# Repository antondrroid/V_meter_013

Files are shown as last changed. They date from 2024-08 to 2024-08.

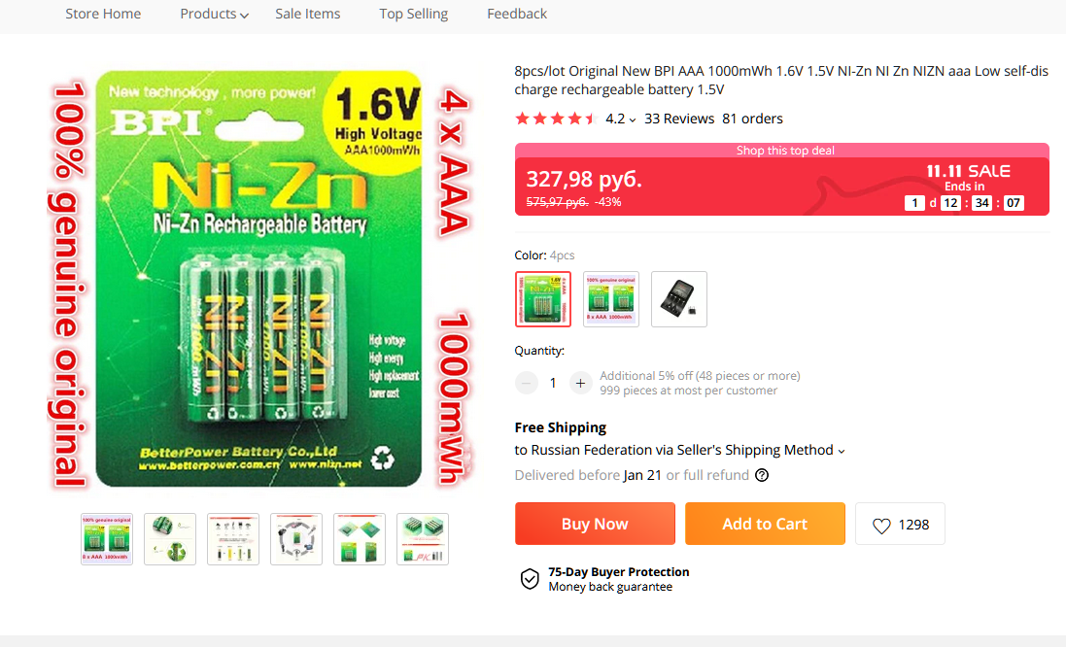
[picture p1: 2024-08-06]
Spare_parts/orders_china_2and3_boards/2021-11-11 22_25_46-8pcs_lot Original New BPI AAA 1000mWh 1.6V 1.5V NI Zn NI Zn NIZN aaa Low self di.png

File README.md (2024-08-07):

# test

hange at remoe and pull to the load.

the somebody edit project

one more time indeendent editing

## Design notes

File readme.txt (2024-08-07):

Initializing a Git repository
the first step is to initialize a Git repository. 

    Open Git Bash.

    Navigate to the root directory of your project.

    Initialize the EMPTY  local directory as a Git repository. By default, the initial branch is called main.

    If you’re using Git 2.28.0 or a later version, you can set the name of the default branch using -b.

    git init -b main

    if this is old git directry, it will reinitialized and in this case need to change owner:
 
              git config --global --add safe.directory D:/projects_old/V_meter/V_meter_013

    Add the files in your new local repository. This stages them for the first commit.

    $ git add .
    # Adds the files in the local repository and stages them for commit. To unstage a file, use 'git reset HEAD YOUR-FILE'.

    Commit the files that you've staged in your local repository.

    $ git commit -m "First commit"
    # Commits the tracked changes and prepares them to be pushed to a remote repository. To remove this commit and modify the file, use 'git reset --soft HEAD~1' and commit and add the file again.

    Adding a local repository to GitHub using Git

Before you can add your local repository to GitHub using Git, you must authenticate to GitHub on the command line. For more information, see "About authentication to GitHub."

    Create a new repository on GitHub.com. To avoid errors, do not initialize the new repository with README, license, or gitignore files. You can add these files after your project has been pushed to GitHub. For more information, see "Creating a new repository."

    At the top of your repository on GitHub.com's Quick Setup page, click 

    to copy the remote repository URL. for example, it will be:

    https://github.com/antondrroid/test_new_local_repository.git

    Screenshot of the "Quick Setup" header in a repository. Next to the remote URL, an icon of two overlapping squares is highlighted with an orange outline.

    Open Git Bash.

    Change the current working directory to your local project.

    To add the URL for the remote repository where your local repository will be pushed, run the following command. Replace REMOTE-URL with the repository's full URL on GitHub.

    git remote add origin https://github.com/antondrroid/test_new_local_repository.git

    For more information, see "Managing remote repositories."

    To verify that you set the remote URL correctly, run the following command.

    git remote -v

answer must be looks like:

            PS D:\projects_old\test_new_local_repository> git remote -v
            origin  https://github.com/antondrroid/test_new_local_repository.git (fetch)
            origin  https://github.com/antondrroid/test_new_local_repository.git (push)

    To push the changes in your local repository to GitHub.com, run the following command.

    git push origin main
if not work, try 
          git push origin /  git push -u origin main
if say:
fatal: The current branch ain has no upstream branch.
To push the current branch and set the remote as upstream, use
       
        git push --set-upstream origin ain

    If your default branch is not named "main," replace "main" with the name of your default branch. For more information, see "About branches."

if remote branch was changed and local has changed too, undepenentaly,
for example, you create in remote file readme.md, but no pushed your loal files to remote yet,
so you has 3 files on local server and one only on remote! 

 use:

PS D:\projects_old\test> git pull origin main
From https://github.com/antondrroid/test
 * branch            main       -> FETCH_HEAD
fatal: refusing to merge unrelated histories  (not syncronized changes, and pull not work as usual)
PS D:\projects_old\test> ls

    Directory: D:\projects_old\test

Mode                 LastWriteTime         Length Name
----                 -------------         ------ ----
d-----          8/6/2024   4:13 PM                contract
-a----          8/6/2024   3:21 PM           3235 readme.txt
-a----          8/6/2024   1:31 PM              0 depth_of_commits.txt

PS D:\projects_old\test> git pull origin main --allow-unrelated-histories
From https://github.com/antondrroid/test
 * branch            main       -> FETCH_HEAD
Merge made by the 'ort' strategy.
 README.md | 1 +
 1 file changed, 1 insertion(+)
 create mode 100644 README.md
PS D:\projects_old\test> ls

after that , use 

git push -u origin main 

and README.MD will be pulled to local server. 

    Directory: D:\projects_old\test

Mode                 LastWriteTime         Length Name
----                 -------------         ------ ----
d-----          8/6/2024   4:13 PM                contract
-a----          8/6/2024   3:21 PM           3235 readme.txt
-a----          8/6/2024   1:31 PM              0 depth_of_commits.txt
-a----          8/6/2024   5:22 PM              8 README.md

if somebody edit he project, while you are trip to  home, and after come, begin edit project, not pul 
before, you will cannot nor pull, nor push.

Further reading

    "Adding a file to a repository"
    "Troubleshooting the 2 GB push limit"

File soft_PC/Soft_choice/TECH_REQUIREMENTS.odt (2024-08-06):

# Состав стенда.

Вольтметр В7-78 c USBtMC портом (3510А) и плата коммутации, управляемая микроконтроллером.

# Описание работы устройства

Вольтметр имеет выход сигнала синхронизации, управляемый командной «триггер», подключеный к входу синхронизации на плате коммутации, которая по команде с микроконтроллера переключает тестовфые выводы на очередную пару контрольнфх точек.

Вольтметр подключен при помощи USB порта к PC.

На PC запускается программа состоящая из пакета команд SPCI, которые конфигурируют установки волтьметра перед измерением, запускают измерение и считывают результтат в файл для последующей обработки результатов. Последней командой в пакете является вызов триггера, в результате которого на выход синхронизации вольтметра подается импульс, воспринимаемый контроллером платы как сигнал к переключению тестовых выводов к следующей паре контрольнфх точек.

# Требования к программному обеспечению

Программное обеспечение представляет собой среду программирования, которая позволяет записывать и хранить пакеты команд SCPI, передавать их через Rs-232 или USBинтерфейс в вольтметр, и принимать результаты измерений и записывать их в любом распостраненном формате в файл для возможности последующей обработки.

<без использования каких либо других языков программирования (JAVA, phyton, C++)>

Желательно в одном из форматов OPEN office / libre office, так как предполагается в дальнейшем изспользовать для работы установки LINUX. Если такого не существует, то в любом из форматов WINDOWS.

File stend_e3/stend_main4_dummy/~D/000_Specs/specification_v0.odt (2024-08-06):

Изм. | Лист | № докум. | Подп. | Дата
Разраб. | | | | | | Лит. | | | Лист | Листов
Пров. | | | | | | | | | 1 | 6
Н.контр.
Утв.

Подп. и дата
Инв. № дубл.
Взам. инв. №
Подп. и дата
Инв. № подл.

Перв. примен.
Справ. №

Копировал

Формат А4

Формат | Зона | Поз. | Обозначение | Наименование | Кол. | Примечание
| | | | Утвержден
| | | | -УД

| | | | | | Лист
| | | | | | 2
Изм. | Лист | № докум. | Подп. | Дата

Подп. и дата
Инв. № дубл.
Взам. инв. №
Подп. и дата
Инв. № подл.

Копировал

Формат А4

Формат | Зона | Поз. | Обозначение | Наименование | Кол. | Примечание

| | | | | | Лист
| | | | | | 3
Изм. | Лист | № докум. | Подп. | Дата

Подп. и дата
Инв. № дубл.
Взам. инв. №
Подп. и дата
Инв. № подл.

Копировал

Формат А4

Формат | Зона | Поз. | Обозначение | Наименование | Кол. | Примечание

Формат | Зона | Поз. | Обозначение | Наименование | Кол. | Примечание

Формат А4

Копировал

Подп. и дата
Инв. № дубл.
Взам. инв. №
Подп. и дата
Инв. № подл.

| | | | | | Лист
| | | | | | 4
Изм. | Лист | № докум. | Подп. | Дата

| | | | | | Лист
| | | | | | 5
Изм. | Лист | № докум. | Подп. | Дата

Подп. и дата
Инв. № дубл.
Взам. инв. №
Подп. и дата
Инв. № подл.

Копировал

Формат А4

Формат | Зона | Поз. | Обозначение | Наименование | Кол. | Примечание

Лист регистрации изменений
Изм. | Номера листов (страниц) | | | | Всего листов (страниц) в докум. | № докум. | Входящий № сопрово- дительного докум. и дата | Подп. | Дата
| изме- ненных | заме- ненных | новых | аннули- рованных

Формат А4

Копировал

Подп. и дата
Инв. № дубл.
Взам. инв. №
Подп. и дата
Инв. № подл.

| | | | | | Лист
| | | | | | 6
Изм. | Лист | № докум. | Подп. | Дата

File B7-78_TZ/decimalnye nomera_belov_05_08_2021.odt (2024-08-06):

RUST.ZM-12.400.00.00 Seebeck measurement system (longitudinally).

Вот таков номер (подчеркнуто) и наименование стенда измерения альфа стержней.

Для механической части: RUST.ZM-12.401.00.00, которая разбивается на RUST.ZM-12.401.01.ХХ, RUST.ZM-12.401.02.УУ

И т.д.

Вам (электронной составляющей) достается номер RUST.ZM-12.402.00.00, который можете разбивать как вам удобно в части 4-х последних цифр.

Далее в состав стенда войдет 3-х контурный термостат со своим источником управления температурой и обеспечением циркуляцией 3-х контуров:

1 контур – внешний - оборотная вода на производстве предприятия.

2 контур - горячий (30 градсов) контур стенда

3 контур – холодный (20 градусов) контур стенда

Мы не будем переделывать всю имеющуюся документация под американский вариант (во всяком случае сейчас).

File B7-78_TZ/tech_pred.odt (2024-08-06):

# Техническое предложение

## по разработке измерительного стенда на основе вольтметра В7-78 с возможностью автоматического измерения параметров в нескольких контрольных точках.

## 1.Состав изделия

Изделие состоит из следующих компонентов :

1.Плата коммутации, предназначенная для переключения измерительных контактов вольтметра на различные контрольные точки.

Переключение осуществляется при помощи механических реле, управляемых микроконтроллером АТМЕГА 328. Управление микроконтроллером осуществляется по программе, предусматривающей передачу управляющих команд от компьютера PC1 на вольтметр MES1 через USB port по интерфейсу USART (RS232), а также использующий внешние входы синхронизации вольтметра MES1.

2.Компьютер PC1, управляющий процессом измерения при помощи команд SCPI, согласно программе написанной на языке С++, а также сохраняющий результаты измерений в виде файла (таблицы) на жестком диске.

3.Вольтметр В7-78, подключенный к плате коммутации измерительными выводами и компьютеру через USB порт.

## 2.Принцип работы изделия.

К выводам каналов коммутационной платы подключаются контрольные точки, в которых необходимо замерить напряжение. Количество контрольных точек неограничено, и хотя в данном проекте предусмотрено 6 каналов, их число может быть увеличено до более чем 32000 (при применении данного контроллера).

После включения питания стенда, запускается программа на компьютере, которая последовательно переключает измерительные выводы к очередному каналу и передает в вольтметр через USB port набор команд SCPI, которые управляют непосредственно процессом измерения параметров для данной контрольной точки и сохраняют результаты в файл на жестом диске компьютера.

###### 3.Предлагаемый порядок работы.

После уточнения ТЗ разрабатывается принципиальная схема*, разводка печатной платы и изготавливается макет платы.

Во время изготовления макета платы проводятся работы по программному обеспечению.

С.Михайлов

*На схеме соединение MCU с каналами управления показаны условно (т.е.пунктиром)

contacts:

т. 89011892586 (whatsupp)

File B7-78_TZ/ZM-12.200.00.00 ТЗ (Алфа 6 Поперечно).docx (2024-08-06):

ZM-12.200.00.00 ТЗ (Алфа 6 Поперечно).

ТЗ.

Назначение

Стенд ZM-12.200.00.00 предназначен для измерения коэффициента термо-эдс (α - К Зеебека) слитков синтезированного термоэлектрического материала на основе теллурида висмута и в форме цилиндров Ø30мм и длиной 140мм. Коэффициента термо-эдс дальнейшем - α.

α удельная величина, определяемая как отношение напряжения (разницы потенциалов) возникающего между двумя участками материала к разнице температур между этими участками. α =(U1-U2)/ΔT

α может быть, как положительной, так и отрицательной величиной в зависимости от типа проводимости материала.

Определение α осуществляется путем измерения:

- разницы потенциалов между двумя точками полупроводника,

- измерения разницы температур между этими точками.

Конструкция теплового узла

Механическая часть стенда представляет собой 2 блока из 12 изложниц каждый в форме полуцилиндрических колец. Температура полуколец одного блока от температуры полуколец второго блока отличается на ~10°С. Всего измеряется 6 слитков. Слитки в процессе измерения находятся между медными полукольцами с различной температурой, причем к слитку прижимается 4 полукольца – по 2-а кольца с одной и другой стороны слитка (слитки в форме стержней диаметром 30мм). Кольца создают разницу температур между боковыми поверхностями слитков с одной и другой стороны каждого из слитков. Температура полуколец поддерживается 2-я водяными контурами. Вода каждого из контуров прокачивается по полукольцам одного из блоков, а ризница температур теплоносителя поддерживается специальным термоэлектрическим блоком. Проток теплоносителя обеспечивается 2-я циркуляционными насосами. В контур с более теплым носителем встроен радиатор с вентилятором, что позволяет сохранять общую среднюю температуру измерений.

В полукольца вмонтированы и подключены как дифференциальный (т.е. навстречу друг другу) термопары, так что можно определить разницу температур между каждыми из 12 пар колец, прилегающими с каждой из сторон слитков. Помимо термопар вмонтированы зонды в виде подпружиненных иголок, по 2-е пары на 2 полукольца.

Алгоритм измерения следующий:

1. Всего в одном цикле измерений определяется термо-эдс 12 слитков. Все 12 слитков относятся к одному процессу синтеза термоэлектрического материала.
2. Укладываются первые 6 слитков на полукольца одного из блоков (холодного) так, что к каждому из слитков прилегает «холодное» полукольцо в начале и в конце слитка. Слитки лежат горизонтально.
3. На 6 слитков опускается блок с ответными 12-ю полукольцами - «горячими». Конструктивно обеспечено, что холодные и горячие кольца расположены встречно образуя 2-а полукольца (горячего и холодного) вокруг слитка. Полукольца подпружинены, для обеспечения хорошего теплового контакта между медными полукольцами и слитками.
4. Время выдержки для стабилизации тепловых условий составляет приблизительно 10 минут.
5. После термостабилизации осуществляется серия автоматических измерений каждое из которых относится к одному из 6-и слитков:
1) Измеряется термо-эдс дифференциальной термопары Uтп (~400мкм) с одной стороны слитка. Значение всегда положительно. Это определяет температуру между горячим и холодным полукольцом с одной стороны слитка.
2) Измеряется разница потенциалов между 2-я парами зондов (от -2000 до +2000мкм) с этой же стороны слитка.
3) Измеряется термо-эдс дифференциальной термопары со второй стороны слитка.
4) Измеряется разница потенциалов между 2-я парами со второй стороны слитка.
6. Измерение по п.4 проводится 6 раз.
7. Далее делается новая закладка из 6-и слитков и измерения по п. 5 и 6 повторяются.

База данных:

В базу данных заносится

1. Дата проведения измерений.
2. Номер процесса синтеза (например 1N3451), состоящий из 3-х идентификационных значений: |X|Y| ZZZZ |

X=1 или 2 или 3 указывает на исходные материалы (первичный синтез, сплавление возвратных материалов и пр до 9.)

Y=N или P указывает тип проводимости синтезируемого материала (только 2-а варианта).

Z= порядковый номер процесса для каждого из сочетаний 1-й и 2-й позиции своя нумерация: т.е. 1N0001, 1P0001, 2N0001, 2P0001…

3. Порядковый номер слитка данного процесса 1…12. Т.е. каждому слитку соответствует не только номер процесса, но и номер слитка в данном процессе.
4. Для каждого слитка соответственно добавляется еще начало и конец слитка.
5. В базу данных измерений заносятся значения измеряемых величин в соответствии с номером процесса, номером слитка и началом или концом слитка.
6. Вместо измеряемых величин в базу данных можно заносить: относящиеся к этому номеру процесса, номеру слитка и позиции в слитке (начало или конец слитка) значения термо-эдс, вычисляемые по формуле:

α 1н= (U11н-U1.2н)/ΔT1н

α 1к= (U11к-U1.2к)/ΔT1к

α 2н= (U21н-U22н)/ΔT2н

α 2к= (U21к-U22к)/ΔT2к

………………………

α12н =(U12.1н-U12.2н)/ΔT12н

α12к =(U12.1к-U12.2к)/ΔT12к

Значение ΔТ определяется из формулы ΔТ= Uтп/40. Для каждого конкретного измерения ΔT1н= U(тп)1н/40.

………………. и т.д. с соответствующими идексами

ΔT12н= U(тп)12н/40.

Значение ΔТ составляет приблизительно 10°С.

7. Значение α должно иметь размерность [мкв/°C]. Ориентировочный диапазон значений от—200 до +200мкм/°С
8. Запрос к базе данных может быть по одному из 3-х параметров или по их сочетанию. Дополнительно необходимо ввести еще 1-о поле для запроса, в котором может быть однозначное число (0-9).

Конструкция блока измерений (электронная часть).

1. Коммутация при переключении измеряемых величин должна осуществляться механическими реле или герконами. Это исключит сетевые и прочие помехи.
2. Измерительная часть должна базироваться на стандартном приборе милливольтметр типа В7-78/2.
3. Точность определяемого значения α должна быть не менее 2% по показаниям электронных приборов. Не учитывается погрешность теплового узла ячеек стенда. Т.е. не учитываем качество тепловых контактов и потерь теплового напора на теплопереходах.
4. Показания значений измеряемых величин (напряжения) должны быть видимы в процессе измерения на цифровой панели измеряющего вольтметра.
5. Вычисленные значения на основании измеряемых величин должны отражаться в протоколе измерений с вычислением среднего значения вычисляемой величины (α) на мониторе компьютера и должна иметься возможность печати протокола.
6. Необходимо иметь протокол по запросу и возможность его напечатать.

Варианты запросов (к базе данных) пока не обсуждались, но для запросов в базе данных достаточно заданного соответствия измеряемых (вычисляемых) величин с идентификатором: дата, тип материалов исходных материалов(X), тип проводимости (Y), номер процесса (ZZZZ), порядковый номер слитка в процессе (1-12), начало и конец слитка.

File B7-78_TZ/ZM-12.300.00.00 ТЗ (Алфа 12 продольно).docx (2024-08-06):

ZM-12.300.00.00 ТЗ (Алфа 12 Продольно).

ТЗ.

Назначение

Стенд ZM-12.300.00.00 предназначен для измерения коэффициента термо-эдс (α - К Зеебека) экструдированных стержней термоэлектрического материала на основе теллурида висмута и в форме цилиндров Ø30мм и длиной 240мм. Коэффициента термо-эдс дальнейшем - α.

α удельная величина, определяемая как отношение напряжения (разницы потенциалов) возникающего между двумя участками материала к разнице температур между этими участками. α =(U1-U2)/ΔT

α может быть, как положительной, так и отрицательной величиной в зависимости от типа проводимости материала.

Определение α осуществляется путем измерения:

- разницы потенциалов между двумя точками полупроводника,

- измерения разницы температур между этими точками.

Конструкция теплового узла

Механическая часть стенда представляет собой 12 ячеек в каждую из которых устанавливается стержень. Каждый стержень устанавливается вертикально на медны блок, температура которого 20гр.С К верхней части стержня прижимается медный блок имеющий температуру 30гр.С. Блоки создают разницу температур между торцевыми поверхностями стержней. Температура блоков поддерживается 2-я водяными контурами. Ризница температур теплоносителя поддерживается специальным термоэлектрическим блоком. Проток теплоносителя обеспечивается 2-я циркуляционными насосами. Температура горячего контура поддерживается специальным блоком управления.

В блоки вмонтированы и подключены как дифференциальный (т.е. навстречу друг другу) термопары, так что можно определить разницу температур между каждыми из 12 пар блоков, прилегающими с каждом из торцов слитков. Помимо термопар к блокам подведены провода, между холодным и горячим блоком каждого стержня (ячейки соответственно) возникает термо-эдс в результате разницы температур (Эффект Зеебека).

Задача: измерить возникающие потенциалы между блоками для каждого стержня и эдс дифференциальной термопары этих блоков, т.е. разницы эдс горячей и холодной термопары..

Алгоритм измерения следующий:

1. Всего в одном цикле измерений определяется термо-эдс 12 слитков. Все 12 слитков относятся к одному процессу экструзии термоэлектрического материала.
2. Устанавливается последовательно каждый из слетков между холодным и горячим блоком.
3. Время выдержки для стабилизации тепловых условий составляет приблизительно 10 минут.
4. После термостабилизации осуществляется серия автоматических измерений каждое из которых относится к одному из 12-и стержней:
1) Измеряется термо-эдс дифференциальной термопары Uтп (~400мкV) с одной стороны слитка. Значение всегда положительно. Это определяет температуру между горячим и холодным полукольцом с одной стороны слитка по формуле: ΔT= Uтп/40
2) Измеряется разница потенциалов между 2-я блоками Uα (от -3000 до +3000мкV) для этого стержня.
5. Измерение по п.1) и 2) проводится 12 раз.
6. В процессе измерения формируется файл относящийся к данному процессу экструзии.

База данных:

В базу данных заносится

1. Дата проведения измерений.
2. Номер процесса экструзии (например 1N3451), состоящий из 3-х идентификационных значений: |X|Y| ZZZZ |

X=1 или 2 или 3 указывает на исходные материалы (первичный синтез, сплавление возвратных материалов и пр до 9.)

Y=N или P указывает тип проводимости синтезируемого материала (только 2-а варианта).

Z= порядковый номер процесса для каждого из сочетаний 1-й и 2-й позиции своя нумерация: т.е. 1N0001, 1P0001, 2N0001, 2P0001…

3. Порядковый номер слитка данного процесса 1…12. Т.е. каждому слитку соответствует не только номер процесса, но и номер слитка в данном процессе.
4. В базу данных измерений заносятся значения измеряемых величин в соответствии с номером процесса и номером слитка.
5. Вместо измеряемых величин в базу данных можно заносить: относящиеся к этому номеру процесса и номеру слитка значения удельной термо-эдс, вычисляемые по формуле:

α 1= Uα1/ ΔT1

α 2= Uα2/ ΔT2

………………………

α 12= Uα12/ ΔT12

Значение ΔТ определяется из формулы ΔТ= Uтп/40. Для каждого конкретного измерения ΔTх= U(тп)х/40.

Значение ΔТ составляет приблизительно 10°С.

6. Значение α должно иметь размерность [мкV/°C]. Ориентировочный диапазон значений от—200 до +200мкм/°С
7. Запрос к базе данных может быть по одному из 3-х параметров или по их сочетанию. Дополнительно необходимо ввести еще 1-о поле для запроса, в котором может быть однозначное число (0-9).

Конструкция блока измерений (электронная часть).

1. Коммутация при переключении измеряемых величин должна осуществляться механическими реле или герконами. Это исключит сетевые и прочие помехи.
2. Измерительная часть должна базироваться на стандартном приборе милливольтметр типа В7-78/2.
3. Точность определяемого значения α должна быть не менее 2% по показаниям электронных приборов. Не учитывается погрешность теплового узла ячеек стенда. Т.е. не учитываем качество тепловых контактов и потерь теплового напора на теплопереходах.
4. Показания значений измеряемых величин (напряжения) должны быть видимы в процессе измерения на цифровой панели измеряющего вольтметра.
5. Вычисленные значения на основании измеряемых величин должны отражаться в протоколе измерений с вычислением среднего значения вычисляемой величины (α) на мониторе компьютера и должна иметься возможность печати протокола.
6. Необходимо иметь протокол по запросу и возможность его напечатать.

Варианты запросов (к базе данных) пока не обсуждались, но для запросов в базе данных достаточно заданного соответствия измеряемых (вычисляемых) величин с идентификатором: дата, тип материалов исходных материалов(X), тип проводимости (Y), номер процесса (ZZZZ), порядковый номер слитка в процессе (1-12), начало и конец слитка.

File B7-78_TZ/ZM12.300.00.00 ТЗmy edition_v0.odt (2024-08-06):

Проект ТЗ.

Разработка блока коммутации для измерительного комплекса

RUST.ZM-12.400.00.00 Seebeck measurement system (longitudinally)

1. Назначение

Блок коммутации предназначен для переключения измерительных контактов измерительного прибора( ИП), входящего в состав комплекса (вольтметра В7-78) между 24 контрольными точками и передачи информации в память входящего в состав комплекса персонального компьютера (ПК), под управлением ОС MS Windows, с подключенным локальным (ЛП) или сетевым принтером (СП) для печати протокола измерений.

2. Принцип работы изделия

Переключения производятся при помощи электромагнитных реле, управляемых при помощи микроконтроллера, который после переключения на очередную контрольную точку дает команду на считывание показаний ИП через интерфейс USB в память ПК, с формированием текстового файла «24.txt».

3. Формат текстового файла

Текстовый файл состоит из строк, по количеству числа измерений. Всего 24 строки.

Первая запись в строке — порядковый номер контрольной точки, в которой проводилось измерение.

Вторая запись — отладочная информация, которая не должна учитываться при дальнейшей работе

Третья запись — значение показания прибора в текущей контрольной точке.

4. Формат показаний прибора и пределы измерений

Пределы измерений прибора устанавливаются в пределах 3000 μV.

запись показаний производится в експоненциальной форме в виде мантиссы и десятичной дроби.

5. Наименование и обозначение изделия.

Изделию присваивается наименование «Блок коммутации» и обозначение «RUST.ZM-12.402.00.00»

Составные части изделия , их наименование и их обозначения выбираются разработчиком, исходя из требований ЕСКД и единого классификатора Общероссийский классификатор изделий и конструкторских документов ОК 012-93

6. Документация

Комплект документации (КД) на изделие должен включать пакет документов, согласно правилам ескд, действующим на момент начала разработки (утверждения ТЗ)

7. Форм фактор.

Изделие размещается в отдельном корпусе из листового металла, на передней и задней панели размещаются выводы для подключения соединителей измерительных контактов, информационных интерфейсов.

На передней панели также размещаются кнопка включения питания изделия и индикатор включения питания изделия.

Корпус может быть использован от имеющейся модели блока либо вновь разработанный.

8. питание

Питание изделия производится от электрической сети с параметрами 220 В, 50 Гц.

9. Перечень имеющихся сокращений

ИП измерительный прибор

КД конструкторская документация

ЛП Локальный принтер

ПК персональный компьютер

СП сетевой принтер

10. Приложения
1. Распечатка образца протокола измерений - 1лист.
2. Эскизная схема соединений комплекса RUST.ZM-12.400.00.00 , с подключенным блоком измерений RUST.ZM-12.402.00.00 .

Утверждаю

Ген. Директор ООО Рустек …..................................

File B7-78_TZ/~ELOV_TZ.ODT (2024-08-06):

1. После термостабилизации осуществляется серия автоматических измерений каждое из которых относится к одному из 6-и слитков:

2. этот пункт предусматривает изучение работы данного вольтметра в автоматическом режиме, а также изучение его языка управления, для этого мне необходимо иметь тестовы1 экземпляр прибора со всей документацией. (если конечно имеется такая возможность, так как в режиме outsourcing на вашей территории я его изучать пока не могу)

3. управление устройством коммутации при помощи MCU не представляет для меня сложности, т..е процесс будет представлять собой поочередное подключение измерительного оборудования к каждому слитку на определенное время синхронизированное с процессом измерения, делаемых вольтметром согласно программе. Такое устройство я могу спроектировать сделать печатную плату и отладить программу контроллера, (полагаю на это уйдет 2 недели или даже больше) но сначала мне необходимо получить информацию по п.2. Имеется ли у вас возможность передать мне данный прибор или есть специалист, который находится в курсе дела и будет заниматься данной частью работы.

4. есть ли у вас предпочитаемая база данных радиоэлементов, чтобы я вибирал элементы для проекта из уже используемых вашей компанией для других изделий?(наверное можете мне передать для этого контакты одного из ваших инженеров - схемотехников. Я пользуюсь Altium Designer)

5. для сохранения целостности переписки прошу вас писать ответы внизу текста.

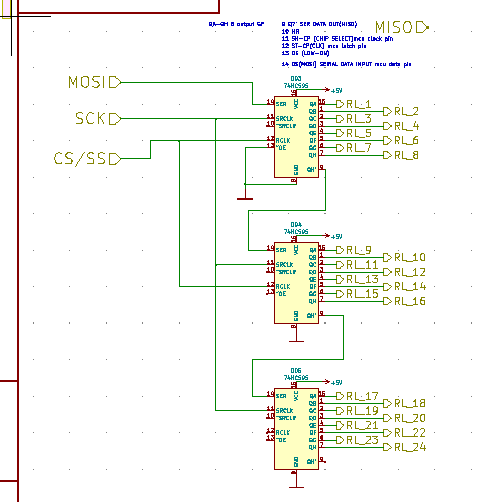
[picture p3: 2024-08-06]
stend_e3/stend_main4_dummy/~rawings/[stend_main_3_REGISTERS_] — Schematic Editor.png

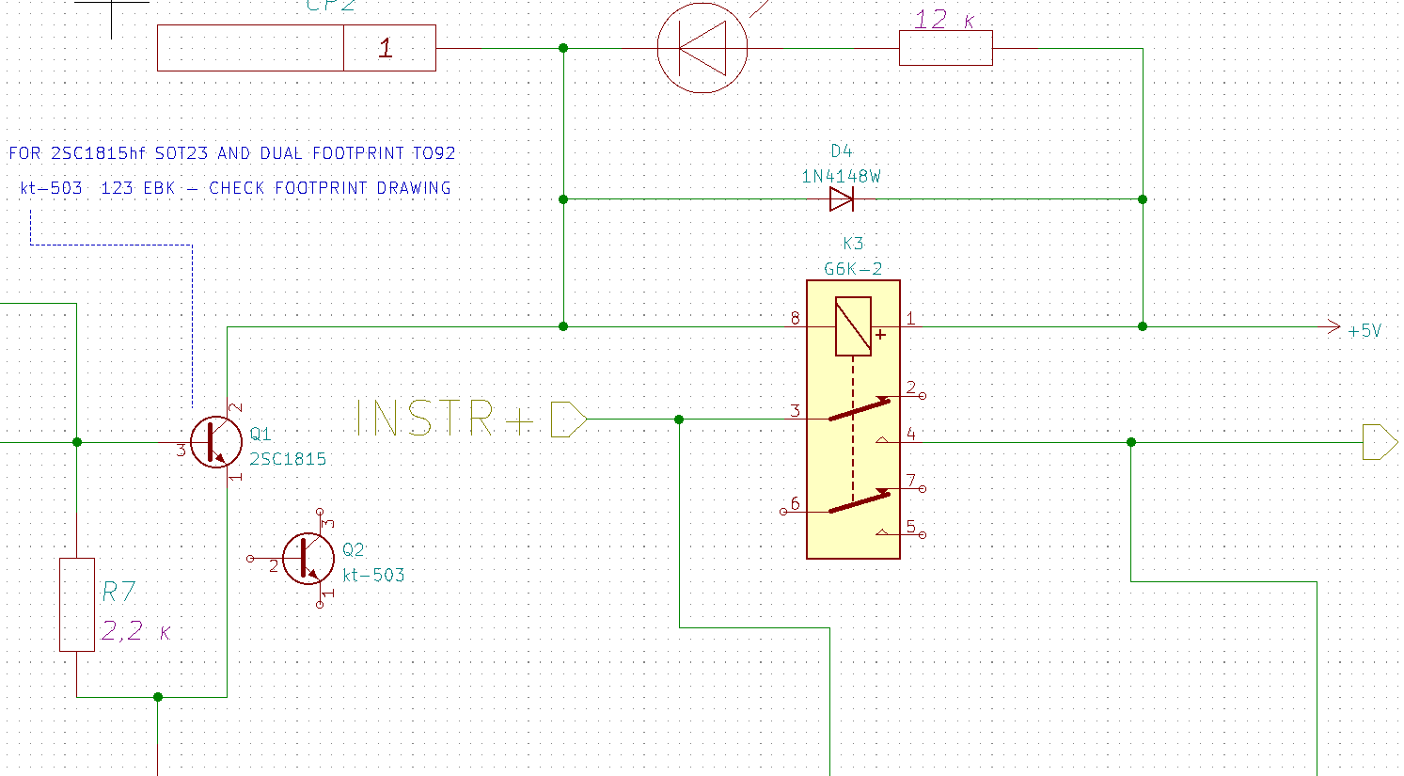
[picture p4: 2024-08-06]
stend_e3/stend_main3/~rawings/2021-09-02 12_52_29-_p5 [stend_main_5_RELAY1_G6K-2F-Y-5VDC_] — Schematic Editor.png

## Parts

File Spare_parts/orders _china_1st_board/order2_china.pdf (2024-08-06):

order2

Page 1

## Заказ 2

назначение | изделие RUST.ZM-12.402.00.00
наименование | Кол-во Цена руб
Модуль микроконтроллера | 2 | 520
Разьем BNC male | 5 | 160
кабель USB/USB B | 1 | 155
resistor 12kom 2 kom SMD (1 набор 300шт) | 1 | 130
resistor 12kom 2 kom углеродные (1 набор400шт)1 | 1 | 140
транзистор 2sc1815 набор 100шт1 | 1 | 105
всего: | 1210

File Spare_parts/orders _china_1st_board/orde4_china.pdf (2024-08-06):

order4

очки монтажные 1-5х | 1 | 1062
увеличительное стекло для часов, 6X, 10X, 15X, 20X, 25X | 1 | 1076
фен паяльный | 1 | 953
паяльная паста BST-510 | 35g | 193
паяльная паста CD LT-528 | 55g | 383
флюсовая паста NC-559-ASM | 3x10cc | 278
Оловянно-свинцовый припой, проволочный | 55g | 214

4159

## Заказ 4 -оборудование и расходные материалы

назначение | изделие RUST.ZM-12.402.00.00
наименование | Кол-во Цена руб

всего:

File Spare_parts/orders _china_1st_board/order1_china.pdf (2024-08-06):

Sheet1

Page 1

наименование | Кол-во | ценаб руб
Реле омрон G6K-2FY | 5 | 143
Реле омрон G6K-2FY | 10 | 315
Реле омрон G6K-2FY | 10 | 365
Реле Fujitsu A5WK | 5 | 288
светодиод SMD | 100 | 128
светодиод плоский | 100 | 98
| | 1337

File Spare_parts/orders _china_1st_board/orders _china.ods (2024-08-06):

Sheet: order1
наименование | Кол-во | ценаб руб
Реле омрон G6K-2FY | 5 | 143
Реле омрон G6K-2FY | 10 | 315
Реле омрон G6K-2FY | 10 | 365
Реле Fujitsu A5WK | 5 | 288
светодиод SMD 0805 | 100 | 128
светодиод плоский | 100 | 98
 |  | 1337

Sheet: order2
Заказ 2
назначение | изделие RUST.ZM-12.402.00.00
наименование | Кол-во | Цена руб
Модуль микроконтроллера | 2 | 520
Разьем BNC male | 5 | 262
кабель USB/USB B | 1 | 159
resistor 12kom 2 kom SMD (1 набор 300шт) | 1 | 130
resistor 12kom 2 kom углеродные (1 набор400шт)1 | 1 | 140
транзистор 2sc1815HF SOT23 набор 100шт1 | 1 | 105
10 штук Разъем PBS-1x16 (PBS-16)шаг 2.54 мм (https://www.aliexpress.ru/item/1005002562703691.html) | 1 | 147
XH2.54 /5/10 p 2,54 мм комплект разъем JST 10шт | 1 | 160
всего: |  | 1623

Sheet: order3
Заказ 3 -замена вместо чипа и дипа
назначение | изделие RUST.ZM-12.402.00.00
наименование | Кол-во | Цена руб
1N4148W SOD-123 | 100 | 92
всего: |  | 92
1N4148 SOD-123

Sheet: order4
Заказ 4 -оборудование и расходные материалы
назначение | изделие RUST.ZM-12.402.00.00
наименование | Кол-во | цена за ед. | Цена общая
очки монтажные 1-5х | 1 |  | 1062
увеличительное стекло для часов, 6X, 10X, 15X, 20X, 25X | 1 |  | 1076
фен паяльный | 1 |  | 953
паяльная паста BST-510 | 35g |  | 193
паяльная паста CD LT-528 | 55g |  | 383
флюсовая паста NC-559-ASM | 3x10cc |  | 278
Оловянно-свинцовый припой, проволочный | 55g |  | 214
гнездо DIP 28 конт, | 10 | 6.9 | 69
оптрон 817 DIP4 PC817 PC817C | 20 | 2.25 | 45
печатная плата макетная | 2 | 70 | 140
всего: |  |  | 4413

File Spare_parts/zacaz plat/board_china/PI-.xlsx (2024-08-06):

 |  |  |  |  | Proforma Invoice
PI NO:20210123-3407297A W202101211743716
Vendor : SHENZHEN JLC ELECTRONICS CO.,LTD. |  |  |  |  |  | Customer:
Contact Person:Roy Fu |  |  |  |  |  | Contact person:I
Tel :+86 755 2391 9769 |  |  |  |  |  | Tel:674609383
Email:support@jlcpcb.com |  |  |  |  |  | Email:
Address: |  |  |  |  |  | Billing Adrdress:
26th Floor, Olympics Building
Shangbao Road, Futian District |  |  |  |  |  | Peremohy
Shenzhen |  |  |  |  |  | 04136
Guangdong |  |  |  |  |  | UKRAINE
China
VAT:
 |  |  |  |  |  | VTA:123456
No. | Description | HS Code | Order No. | QTY |  |  | Unit Price | Amount
1 | PCB Batchs | 8534009000 | P1 | 500 |  |  | 0.2656 | 132.80
Total: |  |  |  |  |  |  |  | $916.70
Note:
 | 1, Payment terms: T/T 100% In Advanced.
 | 2, Customer shall be responsible for the possible transaction fee deducted by bank.
TT Bank Information
Beneficiary's Name: |  | SHENZHEN JLC ELECTRONICS CO.,LTD.
Bank Name: |  | INDUSTRIAL AND COMMERCIAL BANK OF CHINA SHENZHEN BRANCH
Bank Address: |  | North Block Financial Centre Shennan Road East Shenzhen,Guangdong,China
Swift Code: |  | ICBKCNBJSZN
Bank Number: |  | 4000021619090017542
 |  |  |  |  | Approved By |  |  | 2021-09-15

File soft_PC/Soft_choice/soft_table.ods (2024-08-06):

Name of soft | PRO | contra | functions | requirements | price | min price
teststand | emulator absent |  |  |  | $6,000.00 | $2,000.00
diadem | emulator absent |  |  |  | $5,000.00 | $2,000.00
labview | emulator |  |  |  | $6,000.00 | $2,000.00

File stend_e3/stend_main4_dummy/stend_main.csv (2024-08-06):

Source: | D:\V_meter_2\stend_e3\stend_main4_dummy\stend_main.kicad_sch
Date: | 10/23/2021 11:44:15 AM
Tool: | Eeschema (5.99.0-12829-gf2783a86e0)
Generator: | C:\Program Files\KiCad\5.99\bin\scripting\plugins/bom_csv_grouped_by_value.py
Component Count: | 356
Individual Components:
Item | Qty | Reference(s) | Value | LibPart | Footprint | Datasheet | PIN1 | PIN10 | PIN2 | PIN3 | PIN4 | PIN5 | PIN6 | PIN7 | PIN8 | PIN9 | ValueAnalog | ValueC | ValueGOST | ValueGroup | ValueManufacturer | ValueName | ValueNote | ValueSupplier | ValueTU | ValueTemp_1 | ValueTemp_2 | ValueTemp_3 | ValueTemp_4 | ValueTemp_5 | ValueTemperature | volume
 |  | BB1 | bread_16pins | my_Library:bread_16pins | my_Library_ftprint:breadboard_DIP-16_W7.62mm_Socket_LongPads | http://www.ti.com/lit/ds/symlink/sn74hc595.pdf
 |  | BB2 | bread_16pins | my_Library:bread_16pins | my_Library_ftprint:breadboard_DIP-16_W7.62mm_Socket_LongPads | http://www.ti.com/lit/ds/symlink/sn74hc595.pdf
 |  | BB3 | bread_16pins | my_Library:bread_16pins | my_Library_ftprint:breadboard_DIP-16_W7.62mm_Socket_LongPads | http://www.ti.com/lit/ds/symlink/sn74hc595.pdf
 |  | BB4 | bread_16pins | my_Library:bread_16pins | my_Library_ftprint:breadboard_DIP-16_W7.62mm_Socket_LongPads | http://www.ti.com/lit/ds/symlink/sn74hc595.pdf
 |  | BB5 | bread_16pins | my_Library:bread_16pins | my_Library_ftprint:breadboard_DIP-16_W7.62mm_Socket_LongPads | http://www.ti.com/lit/ds/symlink/sn74hc595.pdf
 |  | BB6 | bread_16pins | my_Library:bread_16pins | my_Library_ftprint:breadboard_DIP-16_W7.62mm_Socket_LongPads | http://www.ti.com/lit/ds/symlink/sn74hc595.pdf
 |  | BB7 | bread_16pins | my_Library:bread_16pins | my_Library_ftprint:breadboard_DIP-16_W7.62mm_Socket_LongPads | http://www.ti.com/lit/ds/symlink/sn74hc595.pdf
 |  | C1 | K53-68-C-20V-10uF-10% | [LTM][Capacitors][K53-68][A_B_C_D_E][5]:K53-68-C-20V-10uF-10% | [LTM][FP][Capacitors]:[LTM][C][Tantalum][C][6032-28] | C:/Program Files/KiCad/share/LTM_DataSheet/Конденсаторы_танталовые_К53-68_ОАО_Элеконд.pdf |  |  |  |  |  |  |  |  |  |  | SMD-TAN-C-10uF±10% | 10000000 | К53-68-C-20 В-10 мкФ ±10% | Конденсаторы | ф. ОАО "Элеконд" | 10 мкФ | - | ЗАО "Спец-электронкомплект" | АЖЯР.673546.007 ТУ | АЖЯР.673546.007 ТУ | - | - | - | - | от минус 60 ⁰C до + 125 ⁰C
 |  | CP1 | CP_L | my_Library:CP_L | my_Library_ftprint:PinHeader_1x01_P2.54mm_Vertical |  |  |  |  |  |  |  |  |  |  |  | PLD-10 DS-1021 |  | розетка СНП346-5PП21-1 | Соединители | ф. АО «Электродеталь» | ВИЛКА НА ПЛАТУ 2.5 ММ ШАГ | - | ф. АО «Электродеталь» | РЮМК.430420.011ТУ | РЮМК.430420.011ТУ | - | - | - | - | от минус 60 ⁰C до + 85 ⁰C
 |  | CP2 | CP_L | my_Library:CP_L | my_Library_ftprint:PinHeader_1x01_P2.54mm_Vertical |  |  |  |  |  |  |  |  |  |  |  | PLD-10 DS-1021 |  | розетка СНП346-5PП21-1 | Соединители | ф. АО «Электродеталь» | ВИЛКА НА ПЛАТУ 2.5 ММ ШАГ | - | ф. АО «Электродеталь» | РЮМК.430420.011ТУ | РЮМК.430420.011ТУ | - | - | - | - | от минус 60 ⁰C до + 85 ⁰C
 |  | CP3 | CP_L | my_Library:CP_L | my_Library_ftprint:PinHeader_1x01_P2.54mm_Vertical |  |  |  |  |  |  |  |  |  |  |  | PLD-10 DS-1021 |  | розетка СНП346-5PП21-1 | Соединители | ф. АО «Электродеталь» | ВИЛКА НА ПЛАТУ 2.5 ММ ШАГ | - | ф. АО «Электродеталь» | РЮМК.430420.011ТУ | РЮМК.430420.011ТУ | - | - | - | - | от минус 60 ⁰C до + 85 ⁰C
 |  | CP4 | CP_R | my_Library:CP_R | my_Library_ftprint:PinHeader_1x01_P2.54mm_Vertical |  |  |  |  |  |  |  |  |  |  |  | PLD-10 DS-1021 |  | розетка СНП346-5PП21-1 | Соединители | ф. АО «Электродеталь» | ВИЛКА НА ПЛАТУ 2.5 ММ ШАГ | - | ф. АО «Электродеталь» | РЮМК.430420.011ТУ | РЮМК.430420.011ТУ | - | - | - | - | от минус 60 ⁰C до + 85 ⁰C
 |  | CP5 | CP_L | my_Library:CP_L | my_Library_ftprint:PinHeader_1x01_P2.54mm_Vertical |  |  |  |  |  |  |  |  |  |  |  | PLD-10 DS-1021 |  | розетка СНП346-5PП21-1 | Соединители | ф. АО «Электродеталь» | ВИЛКА НА ПЛАТУ 2.5 ММ ШАГ | - | ф. АО «Электродеталь» | РЮМК.430420.011ТУ | РЮМК.430420.011ТУ | - | - | - | - | от минус 60 ⁰C до + 85 ⁰C
 |  | CP6 | CP_L | my_Library:CP_L | my_Library_ftprint:PinHeader_1x01_P2.54mm_Vertical |  |  |  |  |  |  |  |  |  |  |  | PLD-10 DS-1021 |  | розетка СНП346-5PП21-1 | Соединители | ф. АО «Электродеталь» | ВИЛКА НА ПЛАТУ 2.5 ММ ШАГ | - | ф. АО «Электродеталь» | РЮМК.430420.011ТУ | РЮМК.430420.011ТУ | - | - | - | - | от минус 60 ⁰C до + 85 ⁰C
 |  | CP7 | CP_L | my_Library:CP_L | my_Library_ftprint:PinHeader_1x01_P2.54mm_Vertical |  |  |  |  |  |  |  |  |  |  |  | PLD-10 DS-1021 |  | розетка СНП346-5PП21-1 | Соединители | ф. АО «Электродеталь» | ВИЛКА НА ПЛАТУ 2.5 ММ ШАГ | - | ф. АО «Электродеталь» | РЮМК.430420.011ТУ | РЮМК.430420.011ТУ | - | - | - | - | от минус 60 ⁰C до + 85 ⁰C
 |  | CP8 | CP_R | my_Library:CP_R | my_Library_ftprint:PinHeader_1x01_P2.54mm_Vertical |  |  |  |  |  |  |  |  |  |  |  | PLD-10 DS-1021 |  | розетка СНП346-5PП21-1 | Соединители | ф. АО «Электродеталь» | ВИЛКА НА ПЛАТУ 2.5 ММ ШАГ | - | ф. АО «Электродеталь» | РЮМК.430420.011ТУ | РЮМК.430420.011ТУ | - | - | - | - | от минус 60 ⁰C до + 85 ⁰C
 |  | CP9 | CP_L | my_Library:CP_L | my_Library_ftprint:PinHeader_1x01_P2.54mm_Vertical |  |  |  |  |  |  |  |  |  |  |  | PLD-10 DS-1021 |  | розетка СНП346-5PП21-1 | Соединители | ф. АО «Электродеталь» | ВИЛКА НА ПЛАТУ 2.5 ММ ШАГ | - | ф. АО «Электродеталь» | РЮМК.430420.011ТУ | РЮМК.430420.011ТУ | - | - | - | - | от минус 60 ⁰C до + 85 ⁰C
 |  | CP10 | CP_L | my_Library:CP_L | my_Library_ftprint:PinHeader_1x01_P2.54mm_Vertical |  |  |  |  |  |  |  |  |  |  |  | PLD-10 DS-1021 |  | розетка СНП346-5PП21-1 | Соединители | ф. АО «Электродеталь» | ВИЛКА НА ПЛАТУ 2.5 ММ ШАГ | - | ф. АО «Электродеталь» | РЮМК.430420.011ТУ | РЮМК.430420.011ТУ | - | - | - | - | от минус 60 ⁰C до + 85 ⁰C
 |  | CP11 | CP_L | my_Library:CP_L | my_Library_ftprint:PinHeader_1x01_P2.54mm_Vertical |  |  |  |  |  |  |  |  |  |  |  | PLD-10 DS-1021 |  | розетка СНП346-5PП21-1 | Соединители | ф. АО «Электродеталь» | ВИЛКА НА ПЛАТУ 2.5 ММ ШАГ | - | ф. АО «Электродеталь» | РЮМК.430420.011ТУ | РЮМК.430420.011ТУ | - | - | - | - | от минус 60 ⁰C до + 85 ⁰C
 |  | CP12 | CP_R | my_Library:CP_R | my_Library_ftprint:PinHeader_1x01_P2.54mm_Vertical |  |  |  |  |  |  |  |  |  |  |  | PLD-10 DS-1021 |  | розетка СНП346-5PП21-1 | Соединители | ф. АО «Электродеталь» | ВИЛКА НА ПЛАТУ 2.5 ММ ШАГ | - | ф. АО «Электродеталь» | РЮМК.430420.011ТУ | РЮМК.430420.011ТУ | - | - | - | - | от минус 60 ⁰C до + 85 ⁰C
 |  | CP13 | CP_L | my_Library:CP_L | my_Library_ftprint:PinHeader_1x01_P2.54mm_Vertical |  |  |  |  |  |  |  |  |  |  |  | PLD-10 DS-1021 |  | розетка СНП346-5PП21-1 | Соединители | ф. АО «Электродеталь» | ВИЛКА НА ПЛАТУ 2.5 ММ ШАГ | - | ф. АО «Электродеталь» | РЮМК.430420.011ТУ | РЮМК.430420.011ТУ | - | - | - | - | от минус 60 ⁰C до + 85 ⁰C
 |  | CP14 | CP_L | my_Library:CP_L | my_Library_ftprint:PinHeader_1x01_P2.54mm_Vertical |  |  |  |  |  |  |  |  |  |  |  | PLD-10 DS-1021 |  | розетка СНП346-5PП21-1 | Соединители | ф. АО «Электродеталь» | ВИЛКА НА ПЛАТУ 2.5 ММ ШАГ | - | ф. АО «Электродеталь» | РЮМК.430420.011ТУ | РЮМК.430420.011ТУ | - | - | - | - | от минус 60 ⁰C до + 85 ⁰C
 |  | CP15 | CP_L | my_Library:CP_L | my_Library_ftprint:PinHeader_1x01_P2.54mm_Vertical |  |  |  |  |  |  |  |  |  |  |  | PLD-10 DS-1021 |  | розетка СНП346-5PП21-1 | Соединители | ф. АО «Электродеталь» | ВИЛКА НА ПЛАТУ 2.5 ММ ШАГ | - | ф. АО «Электродеталь» | РЮМК.430420.011ТУ | РЮМК.430420.011ТУ | - | - | - | - | от минус 60 ⁰C до + 85 ⁰C
 |  | CP16 | CP_R | my_Library:CP_R | my_Library_ftprint:PinHeader_1x01_P2.54mm_Vertical |  |  |  |  |  |  |  |  |  |  |  | PLD-10 DS-1021 |  | розетка СНП346-5PП21-1 | Соединители | ф. АО «Электродеталь» | ВИЛКА НА ПЛАТУ 2.5 ММ ШАГ | - | ф. АО «Электродеталь» | РЮМК.430420.011ТУ | РЮМК.430420.011ТУ | - | - | - | - | от минус 60 ⁰C до + 85 ⁰C
 |  | CP17 | CP_L | my_Library:CP_L | my_Library_ftprint:PinHeader_1x01_P2.54mm_Vertical |  |  |  |  |  |  |  |  |  |  |  | PLD-10 DS-1021 |  | розетка СНП346-5PП21-1 | Соединители | ф. АО «Электродеталь» | ВИЛКА НА ПЛАТУ 2.5 ММ ШАГ | - | ф. АО «Электродеталь» | РЮМК.430420.011ТУ | РЮМК.430420.011ТУ | - | - | - | - | от минус 60 ⁰C до + 85 ⁰C
 |  | CP18 | CP_L | my_Library:CP_L | my_Library_ftprint:PinHeader_1x01_P2.54mm_Vertical |  |  |  |  |  |  |  |  |  |  |  | PLD-10 DS-1021 |  | розетка СНП346-5PП21-1 | Соединители | ф. АО «Электродеталь» | ВИЛКА НА ПЛАТУ 2.5 ММ ШАГ | - | ф. АО «Электродеталь» | РЮМК.430420.011ТУ | РЮМК.430420.011ТУ | - | - | - | - | от минус 60 ⁰C до + 85 ⁰C
 |  | CP19 | CP_L | my_Library:CP_L | my_Library_ftprint:PinHeader_1x01_P2.54mm_Vertical |  |  |  |  |  |  |  |  |  |  |  | PLD-10 DS-1021 |  | розетка СНП346-5PП21-1 | Соединители | ф. АО «Электродеталь» | ВИЛКА НА ПЛАТУ 2.5 ММ ШАГ | - | ф. АО «Электродеталь» | РЮМК.430420.011ТУ | РЮМК.430420.011ТУ | - | - | - | - | от минус 60 ⁰C до + 85 ⁰C
 |  | CP20 | CP_R | my_Library:CP_R | my_Library_ftprint:PinHeader_1x01_P2.54mm_Vertical |  |  |  |  |  |  |  |  |  |  |  | PLD-10 DS-1021 |  | розетка СНП346-5PП21-1 | Соединители | ф. АО «Электродеталь» | ВИЛКА НА ПЛАТУ 2.5 ММ ШАГ | - | ф. АО «Электродеталь» | РЮМК.430420.011ТУ | РЮМК.430420.011ТУ | - | - | - | - | от минус 60 ⁰C до + 85 ⁰C
 |  | CP21 | CP_L | my_Library:CP_L | my_Library_ftprint:PinHeader_1x01_P2.54mm_Vertical |  |  |  |  |  |  |  |  |  |  |  | PLD-10 DS-1021 |  | розетка СНП346-5PП21-1 | Соединители | ф. АО «Электродеталь» | ВИЛКА НА ПЛАТУ 2.5 ММ ШАГ | - | ф. АО «Электродеталь» | РЮМК.430420.011ТУ | РЮМК.430420.011ТУ | - | - | - | - | от минус 60 ⁰C до + 85 ⁰C
 |  | CP22 | CP_L | my_Library:CP_L | my_Library_ftprint:PinHeader_1x01_P2.54mm_Vertical |  |  |  |  |  |  |  |  |  |  |  | PLD-10 DS-1021 |  | розетка СНП346-5PП21-1 | Соединители | ф. АО «Электродеталь» | ВИЛКА НА ПЛАТУ 2.5 ММ ШАГ | - | ф. АО «Электродеталь» | РЮМК.430420.011ТУ | РЮМК.430420.011ТУ | - | - | - | - | от минус 60 ⁰C до + 85 ⁰C
 |  | CP23 | CP_L | my_Library:CP_L | my_Library_ftprint:PinHeader_1x01_P2.54mm_Vertical |  |  |  |  |  |  |  |  |  |  |  | PLD-10 DS-1021 |  | розетка СНП346-5PП21-1 | Соединители | ф. АО «Электродеталь» | ВИЛКА НА ПЛАТУ 2.5 ММ ШАГ | - | ф. АО «Электродеталь» | РЮМК.430420.011ТУ | РЮМК.430420.011ТУ | - | - | - | - | от минус 60 ⁰C до + 85 ⁰C
 |  | CP24 | CP_R | my_Library:CP_R | my_Library_ftprint:PinHeader_1x01_P2.54mm_Vertical |  |  |  |  |  |  |  |  |  |  |  | PLD-10 DS-1021 |  | розетка СНП346-5PП21-1 | Соединители | ф. АО «Электродеталь» | ВИЛКА НА ПЛАТУ 2.5 ММ ШАГ | - | ф. АО «Электродеталь» | РЮМК.430420.011ТУ | РЮМК.430420.011ТУ | - | - | - | - | от минус 60 ⁰C до + 85 ⁰C
 |  | CP25 | CP_L | my_Library:CP_L | my_Library_ftprint:PinHeader_1x01_P2.54mm_Vertical |  |  |  |  |  |  |  |  |  |  |  | PLD-10 DS-1021 |  | розетка СНП346-5PП21-1 | Соединители | ф. АО «Электродеталь» | ВИЛКА НА ПЛАТУ 2.5 ММ ШАГ | - | ф. АО «Электродеталь» | РЮМК.430420.011ТУ | РЮМК.430420.011ТУ | - | - | - | - | от минус 60 ⁰C до + 85 ⁰C
 |  | CP26 | CP_L | my_Library:CP_L | my_Library_ftprint:PinHeader_1x01_P2.54mm_Vertical |  |  |  |  |  |  |  |  |  |  |  | PLD-10 DS-1021 |  | розетка СНП346-5PП21-1 | Соединители | ф. АО «Электродеталь» | ВИЛКА НА ПЛАТУ 2.5 ММ ШАГ | - | ф. АО «Электродеталь» | РЮМК.430420.011ТУ | РЮМК.430420.011ТУ | - | - | - | - | от минус 60 ⁰C до + 85 ⁰C
 |  | CP27 | CP_L | my_Library:CP_L | my_Library_ftprint:PinHeader_1x01_P2.54mm_Vertical |  |  |  |  |  |  |  |  |  |  |  | PLD-10 DS-1021 |  | розетка СНП346-5PП21-1 | Соединители | ф. АО «Электродеталь» | ВИЛКА НА ПЛАТУ 2.5 ММ ШАГ | - | ф. АО «Электродеталь» | РЮМК.430420.011ТУ | РЮМК.430420.011ТУ | - | - | - | - | от минус 60 ⁰C до + 85 ⁰C
 |  | CP28 | CP_R | my_Library:CP_R | my_Library_ftprint:PinHeader_1x01_P2.54mm_Vertical |  |  |  |  |  |  |  |  |  |  |  | PLD-10 DS-1021 |  | розетка СНП346-5PП21-1 | Соединители | ф. АО «Электродеталь» | ВИЛКА НА ПЛАТУ 2.5 ММ ШАГ | - | ф. АО «Электродеталь» | РЮМК.430420.011ТУ | РЮМК.430420.011ТУ | - | - | - | - | от минус 60 ⁰C до + 85 ⁰C
 |  | CP29 | CP_L | my_Library:CP_L | my_Library_ftprint:PinHeader_1x01_P2.54mm_Vertical |  |  |  |  |  |  |  |  |  |  |  | PLD-10 DS-1021 |  | розетка СНП346-5PП21-1 | Соединители | ф. АО «Электродеталь» | ВИЛКА НА ПЛАТУ 2.5 ММ ШАГ | - | ф. АО «Электродеталь» | РЮМК.430420.011ТУ | РЮМК.430420.011ТУ | - | - | - | - | от минус 60 ⁰C до + 85 ⁰C
 |  | CP30 | CP_L | my_Library:CP_L | my_Library_ftprint:PinHeader_1x01_P2.54mm_Vertical |  |  |  |  |  |  |  |  |  |  |  | PLD-10 DS-1021 |  | розетка СНП346-5PП21-1 | Соединители | ф. АО «Электродеталь» | ВИЛКА НА ПЛАТУ 2.5 ММ ШАГ | - | ф. АО «Электродеталь» | РЮМК.430420.011ТУ | РЮМК.430420.011ТУ | - | - | - | - | от минус 60 ⁰C до + 85 ⁰C
 |  | CP31 | CP_L | my_Library:CP_L | my_Library_ftprint:PinHeader_1x01_P2.54mm_Vertical |  |  |  |  |  |  |  |  |  |  |  | PLD-10 DS-1021 |  | розетка СНП346-5PП21-1 | Соединители | ф. АО «Электродеталь» | ВИЛКА НА ПЛАТУ 2.5 ММ ШАГ | - | ф. АО «Электродеталь» | РЮМК.430420.011ТУ | РЮМК.430420.011ТУ | - | - | - | - | от минус 60 ⁰C до + 85 ⁰C
 |  | CP32 | CP_R | my_Library:CP_R | my_Library_ftprint:PinHeader_1x01_P2.54mm_Vertical |  |  |  |  |  |  |  |  |  |  |  | PLD-10 DS-1021 |  | розетка СНП346-5PП21-1 | Соединители | ф. АО «Электродеталь» | ВИЛКА НА ПЛАТУ 2.5 ММ ШАГ | - | ф. АО «Электродеталь» | РЮМК.430420.011ТУ | РЮМК.430420.011ТУ | - | - | - | - | от минус 60 ⁰C до + 85 ⁰C
 |  | CP33 | CP_L | my_Library:CP_L | my_Library_ftprint:PinHeader_1x01_P2.54mm_Vertical |  |  |  |  |  |  |  |  |  |  |  | PLD-10 DS-1021 |  | розетка СНП346-5PП21-1 | Соединители | ф. АО «Электродеталь» | ВИЛКА НА ПЛАТУ 2.5 ММ ШАГ | - | ф. АО «Электродеталь» | РЮМК.430420.011ТУ | РЮМК.430420.011ТУ | - | - | - | - | от минус 60 ⁰C до + 85 ⁰C
 |  | CP34 | CP_L | my_Library:CP_L | my_Library_ftprint:PinHeader_1x01_P2.54mm_Vertical |  |  |  |  |  |  |  |  |  |  |  | PLD-10 DS-1021 |  | розетка СНП346-5PП21-1 | Соединители | ф. АО «Электродеталь» | ВИЛКА НА ПЛАТУ 2.5 ММ ШАГ | - | ф. АО «Электродеталь» | РЮМК.430420.011ТУ | РЮМК.430420.011ТУ | - | - | - | - | от минус 60 ⁰C до + 85 ⁰C
 |  | CP35 | CP_L | my_Library:CP_L | my_Library_ftprint:PinHeader_1x01_P2.54mm_Vertical |  |  |  |  |  |  |  |  |  |  |  | PLD-10 DS-1021 |  | розетка СНП346-5PП21-1 | Соединители | ф. АО «Электродеталь» | ВИЛКА НА ПЛАТУ 2.5 ММ ШАГ | - | ф. АО «Электродеталь» | РЮМК.430420.011ТУ | РЮМК.430420.011ТУ | - | - | - | - | от минус 60 ⁰C до + 85 ⁰C
 |  | CP36 | CP_R | my_Library:CP_R | my_Library_ftprint:PinHeader_1x01_P2.54mm_Vertical |  |  |  |  |  |  |  |  |  |  |  | PLD-10 DS-1021 |  | розетка СНП346-5PП21-1 | Соединители | ф. АО «Электродеталь» | ВИЛКА НА ПЛАТУ 2.5 ММ ШАГ | - | ф. АО «Электродеталь» | РЮМК.430420.011ТУ | РЮМК.430420.011ТУ | - | - | - | - | от минус 60 ⁰C до + 85 ⁰C
 |  | CP37 | CP_L | my_Library:CP_L | my_Library_ftprint:PinHeader_1x01_P2.54mm_Vertical |  |  |  |  |  |  |  |  |  |  |  | PLD-10 DS-1021 |  | розетка СНП346-5PП21-1 | Соединители | ф. АО «Электродеталь» | ВИЛКА НА ПЛАТУ 2.5 ММ ШАГ | - | ф. АО «Электродеталь» | РЮМК.430420.011ТУ | РЮМК.430420.011ТУ | - | - | - | - | от минус 60 ⁰C до + 85 ⁰C
 |  | CP38 | CP_L | my_Library:CP_L | my_Library_ftprint:PinHeader_1x01_P2.54mm_Vertical |  |  |  |  |  |  |  |  |  |  |  | PLD-10 DS-1021 |  | розетка СНП346-5PП21-1 | Соединители | ф. АО «Электродеталь» | ВИЛКА НА ПЛАТУ 2.5 ММ ШАГ | - | ф. АО «Электродеталь» | РЮМК.430420.011ТУ | РЮМК.430420.011ТУ | - | - | - | - | от минус 60 ⁰C до + 85 ⁰C
 |  | CP39 | CP_L | my_Library:CP_L | my_Library_ftprint:PinHeader_1x01_P2.54mm_Vertical |  |  |  |  |  |  |  |  |  |  |  | PLD-10 DS-1021 |  | розетка СНП346-5PП21-1 | Соединители | ф. АО «Электродеталь» | ВИЛКА НА ПЛАТУ 2.5 ММ ШАГ | - | ф. АО «Электродеталь» | РЮМК.430420.011ТУ | РЮМК.430420.011ТУ | - | - | - | - | от минус 60 ⁰C до + 85 ⁰C
 |  | CP40 | CP_R | my_Library:CP_R | my_Library_ftprint:PinHeader_1x01_P2.54mm_Vertical |  |  |  |  |  |  |  |  |  |  |  | PLD-10 DS-1021 |  | розетка СНП346-5PП21-1 | Соединители | ф. АО «Электродеталь» | ВИЛКА НА ПЛАТУ 2.5 ММ ШАГ | - | ф. АО «Электродеталь» | РЮМК.430420.011ТУ | РЮМК.430420.011ТУ | - | - | - | - | от минус 60 ⁰C до + 85 ⁰C
 |  | CP41 | CP_L | my_Library:CP_L | my_Library_ftprint:PinHeader_1x01_P2.54mm_Vertical |  |  |  |  |  |  |  |  |  |  |  | PLD-10 DS-1021 |  | розетка СНП346-5PП21-1 | Соединители | ф. АО «Электродеталь» | ВИЛКА НА ПЛАТУ 2.5 ММ ШАГ | - | ф. АО «Электродеталь» | РЮМК.430420.011ТУ | РЮМК.430420.011ТУ | - | - | - | - | от минус 60 ⁰C до + 85 ⁰C
 |  | CP42 | CP_L | my_Library:CP_L | my_Library_ftprint:PinHeader_1x01_P2.54mm_Vertical |  |  |  |  |  |  |  |  |  |  |  | PLD-10 DS-1021 |  | розетка СНП346-5PП21-1 | Соединители | ф. АО «Электродеталь» | ВИЛКА НА ПЛАТУ 2.5 ММ ШАГ | - | ф. АО «Электродеталь» | РЮМК.430420.011ТУ | РЮМК.430420.011ТУ | - | - | - | - | от минус 60 ⁰C до + 85 ⁰C
 |  | CP43 | CP_L | my_Library:CP_L | my_Library_ftprint:PinHeader_1x01_P2.54mm_Vertical |  |  |  |  |  |  |  |  |  |  |  | PLD-10 DS-1021 |  | розетка СНП346-5PП21-1 | Соединители | ф. АО «Электродеталь» | ВИЛКА НА ПЛАТУ 2.5 ММ ШАГ | - | ф. АО «Электродеталь» | РЮМК.430420.011ТУ | РЮМК.430420.011ТУ | - | - | - | - | от минус 60 ⁰C до + 85 ⁰C
 |  | CP44 | CP_R | my_Library:CP_R | my_Library_ftprint:PinHeader_1x01_P2.54mm_Vertical |  |  |  |  |  |  |  |  |  |  |  | PLD-10 DS-1021 |  | розетка СНП346-5PП21-1 | Соединители | ф. АО «Электродеталь» | ВИЛКА НА ПЛАТУ 2.5 ММ ШАГ | - | ф. АО «Электродеталь» | РЮМК.430420.011ТУ | РЮМК.430420.011ТУ | - | - | - | - | от минус 60 ⁰C до + 85 ⁰C
 |  | CP45 | CP_L | my_Library:CP_L | my_Library_ftprint:PinHeader_1x01_P2.54mm_Vertical |  |  |  |  |  |  |  |  |  |  |  | PLD-10 DS-1021 |  | розетка СНП346-5PП21-1 | Соединители | ф. АО «Электродеталь» | ВИЛКА НА ПЛАТУ 2.5 ММ ШАГ | - | ф. АО «Электродеталь» | РЮМК.430420.011ТУ | РЮМК.430420.011ТУ | - | - | - | - | от минус 60 ⁰C до + 85 ⁰C
 |  | CP46 | CP_L | my_Library:CP_L | my_Library_ftprint:PinHeader_1x01_P2.54mm_Vertical |  |  |  |  |  |  |  |  |  |  |  | PLD-10 DS-1021 |  | розетка СНП346-5PП21-1 | Соединители | ф. АО «Электродеталь» | ВИЛКА НА ПЛАТУ 2.5 ММ ШАГ | - | ф. АО «Электродеталь» | РЮМК.430420.011ТУ | РЮМК.430420.011ТУ | - | - | - | - | от минус 60 ⁰C до + 85 ⁰C
 |  | CP47 | CP_L | my_Library:CP_L | my_Library_ftprint:PinHeader_1x01_P2.54mm_Vertical |  |  |  |  |  |  |  |  |  |  |  | PLD-10 DS-1021 |  | розетка СНП346-5PП21-1 | Соединители | ф. АО «Электродеталь» | ВИЛКА НА ПЛАТУ 2.5 ММ ШАГ | - | ф. АО «Электродеталь» | РЮМК.430420.011ТУ | РЮМК.430420.011ТУ | - | - | - | - | от минус 60 ⁰C до + 85 ⁰C
 |  | CP48 | CP_R | my_Library:CP_R | my_Library_ftprint:PinHeader_1x01_P2.54mm_Vertical |  |  |  |  |  |  |  |  |  |  |  | PLD-10 DS-1021 |  | розетка СНП346-5PП21-1 | Соединители | ф. АО «Электродеталь» | ВИЛКА НА ПЛАТУ 2.5 ММ ШАГ | - | ф. АО «Электродеталь» | РЮМК.430420.011ТУ | РЮМК.430420.011ТУ | - | - | - | - | от минус 60 ⁰C до + 85 ⁰C
 |  | CP49 | CP_L | my_Library:CP_L | my_Library_ftprint:PinHeader_1x01_P2.54mm_Vertical |  |  |  |  |  |  |  |  |  |  |  | PLD-10 DS-1021 |  | розетка СНП346-5PП21-1 | Соединители | ф. АО «Электродеталь» | ВИЛКА НА ПЛАТУ 2.5 ММ ШАГ | - | ф. АО «Электродеталь» | РЮМК.430420.011ТУ | РЮМК.430420.011ТУ | - | - | - | - | от минус 60 ⁰C до + 85 ⁰C
 |  | CP50 | CP_L | my_Library:CP_L | my_Library_ftprint:PinHeader_1x01_P2.54mm_Vertical |  |  |  |  |  |  |  |  |  |  |  | PLD-10 DS-1021 |  | розетка СНП346-5PП21-1 | Соединители | ф. АО «Электродеталь» | ВИЛКА НА ПЛАТУ 2.5 ММ ШАГ | - | ф. АО «Электродеталь» | РЮМК.430420.011ТУ | РЮМК.430420.011ТУ | - | - | - | - | от минус 60 ⁰C до + 85 ⁰C
 |  | CP51 | CP_L | my_Library:CP_L | my_Library_ftprint:PinHeader_1x01_P2.54mm_Vertical |  |  |  |  |  |  |  |  |  |  |  | PLD-10 DS-1021 |  | розетка СНП346-5PП21-1 | Соединители | ф. АО «Электродеталь» | ВИЛКА НА ПЛАТУ 2.5 ММ ШАГ | - | ф. АО «Электродеталь» | РЮМК.430420.011ТУ | РЮМК.430420.011ТУ | - | - | - | - | от минус 60 ⁰C до + 85 ⁰C
 |  | CP52 | CP_R | my_Library:CP_R | my_Library_ftprint:PinHeader_1x01_P2.54mm_Vertical |  |  |  |  |  |  |  |  |  |  |  | PLD-10 DS-1021 |  | розетка СНП346-5PП21-1 | Соединители | ф. АО «Электродеталь» | ВИЛКА НА ПЛАТУ 2.5 ММ ШАГ | - | ф. АО «Электродеталь» | РЮМК.430420.011ТУ | РЮМК.430420.011ТУ | - | - | - | - | от минус 60 ⁰C до + 85 ⁰C
 |  | CP53 | CP_L | my_Library:CP_L | my_Library_ftprint:PinHeader_1x01_P2.54mm_Vertical |  |  |  |  |  |  |  |  |  |  |  | PLD-10 DS-1021 |  | розетка СНП346-5PП21-1 | Соединители | ф. АО «Электродеталь» | ВИЛКА НА ПЛАТУ 2.5 ММ ШАГ | - | ф. АО «Электродеталь» | РЮМК.430420.011ТУ | РЮМК.430420.011ТУ | - | - | - | - | от минус 60 ⁰C до + 85 ⁰C
 |  | CP54 | CP_L | my_Library:CP_L | my_Library_ftprint:PinHeader_1x01_P2.54mm_Vertical |  |  |  |  |  |  |  |  |  |  |  | PLD-10 DS-1021 |  | розетка СНП346-5PП21-1 | Соединители | ф. АО «Электродеталь» | ВИЛКА НА ПЛАТУ 2.5 ММ ШАГ | - | ф. АО «Электродеталь» | РЮМК.430420.011ТУ | РЮМК.430420.011ТУ | - | - | - | - | от минус 60 ⁰C до + 85 ⁰C
 |  | CP55 | CP_L | my_Library:CP_L | my_Library_ftprint:PinHeader_1x01_P2.54mm_Vertical |  |  |  |  |  |  |  |  |  |  |  | PLD-10 DS-1021 |  | розетка СНП346-5PП21-1 | Соединители | ф. АО «Электродеталь» | ВИЛКА НА ПЛАТУ 2.5 ММ ШАГ | - | ф. АО «Электродеталь» | РЮМК.430420.011ТУ | РЮМК.430420.011ТУ | - | - | - | - | от минус 60 ⁰C до + 85 ⁰C
 |  | CP56 | CP_R | my_Library:CP_R | my_Library_ftprint:PinHeader_1x01_P2.54mm_Vertical |  |  |  |  |  |  |  |  |  |  |  | PLD-10 DS-1021 |  | розетка СНП346-5PП21-1 | Соединители | ф. АО «Электродеталь» | ВИЛКА НА ПЛАТУ 2.5 ММ ШАГ | - | ф. АО «Электродеталь» | РЮМК.430420.011ТУ | РЮМК.430420.011ТУ | - | - | - | - | от минус 60 ⁰C до + 85 ⁰C
 |  | CP57 | CP_L | my_Library:CP_L | my_Library_ftprint:PinHeader_1x01_P2.54mm_Vertical |  |  |  |  |  |  |  |  |  |  |  | PLD-10 DS-1021 |  | розетка СНП346-5PП21-1 | Соединители | ф. АО «Электродеталь» | ВИЛКА НА ПЛАТУ 2.5 ММ ШАГ | - | ф. АО «Электродеталь» | РЮМК.430420.011ТУ | РЮМК.430420.011ТУ | - | - | - | - | от минус 60 ⁰C до + 85 ⁰C
 |  | CP58 | CP_L | my_Library:CP_L | my_Library_ftprint:PinHeader_1x01_P2.54mm_Vertical |  |  |  |  |  |  |  |  |  |  |  | PLD-10 DS-1021 |  | розетка СНП346-5PП21-1 | Соединители | ф. АО «Электродеталь» | ВИЛКА НА ПЛАТУ 2.5 ММ ШАГ | - | ф. АО «Электродеталь» | РЮМК.430420.011ТУ | РЮМК.430420.011ТУ | - | - | - | - | от минус 60 ⁰C до + 85 ⁰C
 |  | CP59 | CP_L | my_Library:CP_L | my_Library_ftprint:PinHeader_1x01_P2.54mm_Vertical |  |  |  |  |  |  |  |  |  |  |  | PLD-10 DS-1021 |  | розетка СНП346-5PП21-1 | Соединители | ф. АО «Электродеталь» | ВИЛКА НА ПЛАТУ 2.5 ММ ШАГ | - | ф. АО «Электродеталь» | РЮМК.430420.011ТУ | РЮМК.430420.011ТУ | - | - | - | - | от минус 60 ⁰C до + 85 ⁰C
 |  | CP60 | CP_R | my_Library:CP_R | my_Library_ftprint:PinHeader_1x01_P2.54mm_Vertical |  |  |  |  |  |  |  |  |  |  |  | PLD-10 DS-1021 |  | розетка СНП346-5PП21-1 | Соединители | ф. АО «Электродеталь» | ВИЛКА НА ПЛАТУ 2.5 ММ ШАГ | - | ф. АО «Электродеталь» | РЮМК.430420.011ТУ | РЮМК.430420.011ТУ | - | - | - | - | от минус 60 ⁰C до + 85 ⁰C
 |  | CP61 | CP_L | my_Library:CP_L | my_Library_ftprint:PinHeader_1x01_P2.54mm_Vertical |  |  |  |  |  |  |  |  |  |  |  | PLD-10 DS-1021 |  | розетка СНП346-5PП21-1 | Соединители | ф. АО «Электродеталь» | ВИЛКА НА ПЛАТУ 2.5 ММ ШАГ | - | ф. АО «Электродеталь» | РЮМК.430420.011ТУ | РЮМК.430420.011ТУ | - | - | - | - | от минус 60 ⁰C до + 85 ⁰C
 |  | CP62 | CP_L | my_Library:CP_L | my_Library_ftprint:PinHeader_1x01_P2.54mm_Vertical |  |  |  |  |  |  |  |  |  |  |  | PLD-10 DS-1021 |  | розетка СНП346-5PП21-1 | Соединители | ф. АО «Электродеталь» | ВИЛКА НА ПЛАТУ 2.5 ММ ШАГ | - | ф. АО «Электродеталь» | РЮМК.430420.011ТУ | РЮМК.430420.011ТУ | - | - | - | - | от минус 60 ⁰C до + 85 ⁰C
 |  | CP63 | CP_L | my_Library:CP_L | my_Library_ftprint:PinHeader_1x01_P2.54mm_Vertical |  |  |  |  |  |  |  |  |  |  |  | PLD-10 DS-1021 |  | розетка СНП346-5PП21-1 | Соединители | ф. АО «Электродеталь» | ВИЛКА НА ПЛАТУ 2.5 ММ ШАГ | - | ф. АО «Электродеталь» | РЮМК.430420.011ТУ | РЮМК.430420.011ТУ | - | - | - | - | от минус 60 ⁰C до + 85 ⁰C
 |  | CP64 | CP_R | my_Library:CP_R | my_Library_ftprint:PinHeader_1x01_P2.54mm_Vertical |  |  |  |  |  |  |  |  |  |  |  | PLD-10 DS-1021 |  | розетка СНП346-5PП21-1 | Соединители | ф. АО «Электродеталь» | ВИЛКА НА ПЛАТУ 2.5 ММ ШАГ | - | ф. АО «Электродеталь» | РЮМК.430420.011ТУ | РЮМК.430420.011ТУ | - | - | - | - | от минус 60 ⁰C до + 85 ⁰C
 |  | CP65 | CP_L | my_Library:CP_L | my_Library_ftprint:PinHeader_1x01_P2.54mm_Vertical |  |  |  |  |  |  |  |  |  |  |  | PLD-10 DS-1021 |  | розетка СНП346-5PП21-1 | Соединители | ф. АО «Электродеталь» | ВИЛКА НА ПЛАТУ 2.5 ММ ШАГ | - | ф. АО «Электродеталь» | РЮМК.430420.011ТУ | РЮМК.430420.011ТУ | - | - | - | - | от минус 60 ⁰C до + 85 ⁰C
 |  | CP66 | CP_L | my_Library:CP_L | my_Library_ftprint:PinHeader_1x01_P2.54mm_Vertical |  |  |  |  |  |  |  |  |  |  |  | PLD-10 DS-1021 |  | розетка СНП346-5PП21-1 | Соединители | ф. АО «Электродеталь» | ВИЛКА НА ПЛАТУ 2.5 ММ ШАГ | - | ф. АО «Электродеталь» | РЮМК.430420.011ТУ | РЮМК.430420.011ТУ | - | - | - | - | от минус 60 ⁰C до + 85 ⁰C
 |  | CP67 | CP_L | my_Library:CP_L | my_Library_ftprint:PinHeader_1x01_P2.54mm_Vertical |  |  |  |  |  |  |  |  |  |  |  | PLD-10 DS-1021 |  | розетка СНП346-5PП21-1 | Соединители | ф. АО «Электродеталь» | ВИЛКА НА ПЛАТУ 2.5 ММ ШАГ | - | ф. АО «Электродеталь» | РЮМК.430420.011ТУ | РЮМК.430420.011ТУ | - | - | - | - | от минус 60 ⁰C до + 85 ⁰C
 |  | CP68 | CP_R | my_Library:CP_R | my_Library_ftprint:PinHeader_1x01_P2.54mm_Vertical |  |  |  |  |  |  |  |  |  |  |  | PLD-10 DS-1021 |  | розетка СНП346-5PП21-1 | Соединители | ф. АО «Электродеталь» | ВИЛКА НА ПЛАТУ 2.5 ММ ШАГ | - | ф. АО «Электродеталь» | РЮМК.430420.011ТУ | РЮМК.430420.011ТУ | - | - | - | - | от минус 60 ⁰C до + 85 ⁰C
 |  | CP69 | CP_L | my_Library:CP_L | my_Library_ftprint:PinHeader_1x01_P2.54mm_Vertical |  |  |  |  |  |  |  |  |  |  |  | PLD-10 DS-1021 |  | розетка СНП346-5PП21-1 | Соединители | ф. АО «Электродеталь» | ВИЛКА НА ПЛАТУ 2.5 ММ ШАГ | - | ф. АО «Электродеталь» | РЮМК.430420.011ТУ | РЮМК.430420.011ТУ | - | - | - | - | от минус 60 ⁰C до + 85 ⁰C
 |  | CP70 | CP_L | my_Library:CP_L | my_Library_ftprint:PinHeader_1x01_P2.54mm_Vertical |  |  |  |  |  |  |  |  |  |  |  | PLD-10 DS-1021 |  | розетка СНП346-5PП21-1 | Соединители | ф. АО «Электродеталь» | ВИЛКА НА ПЛАТУ 2.5 ММ ШАГ | - | ф. АО «Электродеталь» | РЮМК.430420.011ТУ | РЮМК.430420.011ТУ | - | - | - | - | от минус 60 ⁰C до + 85 ⁰C
 |  | CP71 | CP_L | my_Library:CP_L | my_Library_ftprint:PinHeader_1x01_P2.54mm_Vertical |  |  |  |  |  |  |  |  |  |  |  | PLD-10 DS-1021 |  | розетка СНП346-5PП21-1 | Соединители | ф. АО «Электродеталь» | ВИЛКА НА ПЛАТУ 2.5 ММ ШАГ | - | ф. АО «Электродеталь» | РЮМК.430420.011ТУ | РЮМК.430420.011ТУ | - | - | - | - | от минус 60 ⁰C до + 85 ⁰C
 |  | CP72 | CP_R | my_Library:CP_R | my_Library_ftprint:PinHeader_1x01_P2.54mm_Vertical |  |  |  |  |  |  |  |  |  |  |  | PLD-10 DS-1021 |  | розетка СНП346-5PП21-1 | Соединители | ф. АО «Электродеталь» | ВИЛКА НА ПЛАТУ 2.5 ММ ШАГ | - | ф. АО «Электродеталь» | РЮМК.430420.011ТУ | РЮМК.430420.011ТУ | - | - | - | - | от минус 60 ⁰C до + 85 ⁰C
 |  | CP73 | CP_L | my_Library:CP_L | my_Library_ftprint:PinHeader_1x01_P2.54mm_Vertical |  |  |  |  |  |  |  |  |  |  |  | PLD-10 DS-1021 |  | розетка СНП346-5PП21-1 | Соединители | ф. АО «Электродеталь» | ВИЛКА НА ПЛАТУ 2.5 ММ ШАГ | - | ф. АО «Электродеталь» | РЮМК.430420.011ТУ | РЮМК.430420.011ТУ | - | - | - | - | от минус 60 ⁰C до + 85 ⁰C
 |  | CP74 | CP_L | my_Library:CP_L | my_Library_ftprint:PinHeader_1x01_P2.54mm_Vertical |  |  |  |  |  |  |  |  |  |  |  | PLD-10 DS-1021 |  | розетка СНП346-5PП21-1 | Соединители | ф. АО «Электродеталь» | ВИЛКА НА ПЛАТУ 2.5 ММ ШАГ | - | ф. АО «Электродеталь» | РЮМК.430420.011ТУ | РЮМК.430420.011ТУ | - | - | - | - | от минус 60 ⁰C до + 85 ⁰C
 |  | CP75 | CP_L | my_Library:CP_L | my_Library_ftprint:PinHeader_1x01_P2.54mm_Vertical |  |  |  |  |  |  |  |  |  |  |  | PLD-10 DS-1021 |  | розетка СНП346-5PП21-1 | Соединители | ф. АО «Электродеталь» | ВИЛКА НА ПЛАТУ 2.5 ММ ШАГ | - | ф. АО «Электродеталь» | РЮМК.430420.011ТУ | РЮМК.430420.011ТУ | - | - | - | - | от минус 60 ⁰C до + 85 ⁰C
 |  | CP76 | CP_R | my_Library:CP_R | my_Library_ftprint:PinHeader_1x01_P2.54mm_Vertical |  |  |  |  |  |  |  |  |  |  |  | PLD-10 DS-1021 |  | розетка СНП346-5PП21-1 | Соединители | ф. АО «Электродеталь» | ВИЛКА НА ПЛАТУ 2.5 ММ ШАГ | - | ф. АО «Электродеталь» | РЮМК.430420.011ТУ | РЮМК.430420.011ТУ | - | - | - | - | от минус 60 ⁰C до + 85 ⁰C
 |  | CP77 | CP_L | my_Library:CP_L | my_Library_ftprint:PinHeader_1x01_P2.54mm_Vertical |  |  |  |  |  |  |  |  |  |  |  | PLD-10 DS-1021 |  | розетка СНП346-5PП21-1 | Соединители | ф. АО «Электродеталь» | ВИЛКА НА ПЛАТУ 2.5 ММ ШАГ | - | ф. АО «Электродеталь» | РЮМК.430420.011ТУ | РЮМК.430420.011ТУ | - | - | - | - | от минус 60 ⁰C до + 85 ⁰C
 |  | CP78 | CP_L | my_Library:CP_L | my_Library_ftprint:PinHeader_1x01_P2.54mm_Vertical |  |  |  |  |  |  |  |  |  |  |  | PLD-10 DS-1021 |  | розетка СНП346-5PП21-1 | Соединители | ф. АО «Электродеталь» | ВИЛКА НА ПЛАТУ 2.5 ММ ШАГ | - | ф. АО «Электродеталь» | РЮМК.430420.011ТУ | РЮМК.430420.011ТУ | - | - | - | - | от минус 60 ⁰C до + 85 ⁰C
 |  | CP79 | CP_L | my_Library:CP_L | my_Library_ftprint:PinHeader_1x01_P2.54mm_Vertical |  |  |  |  |  |  |  |  |  |  |  | PLD-10 DS-1021 |  | розетка СНП346-5PП21-1 | Соединители | ф. АО «Электродеталь» | ВИЛКА НА ПЛАТУ 2.5 ММ ШАГ | - | ф. АО «Электродеталь» | РЮМК.430420.011ТУ | РЮМК.430420.011ТУ | - | - | - | - | от минус 60 ⁰C до + 85 ⁰C
 |  | CP80 | CP_R | my_Library:CP_R | my_Library_ftprint:PinHeader_1x01_P2.54mm_Vertical |  |  |  |  |  |  |  |  |  |  |  | PLD-10 DS-1021 |  | розетка СНП346-5PП21-1 | Соединители | ф. АО «Электродеталь» | ВИЛКА НА ПЛАТУ 2.5 ММ ШАГ | - | ф. АО «Электродеталь» | РЮМК.430420.011ТУ | РЮМК.430420.011ТУ | - | - | - | - | от минус 60 ⁰C до + 85 ⁰C
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

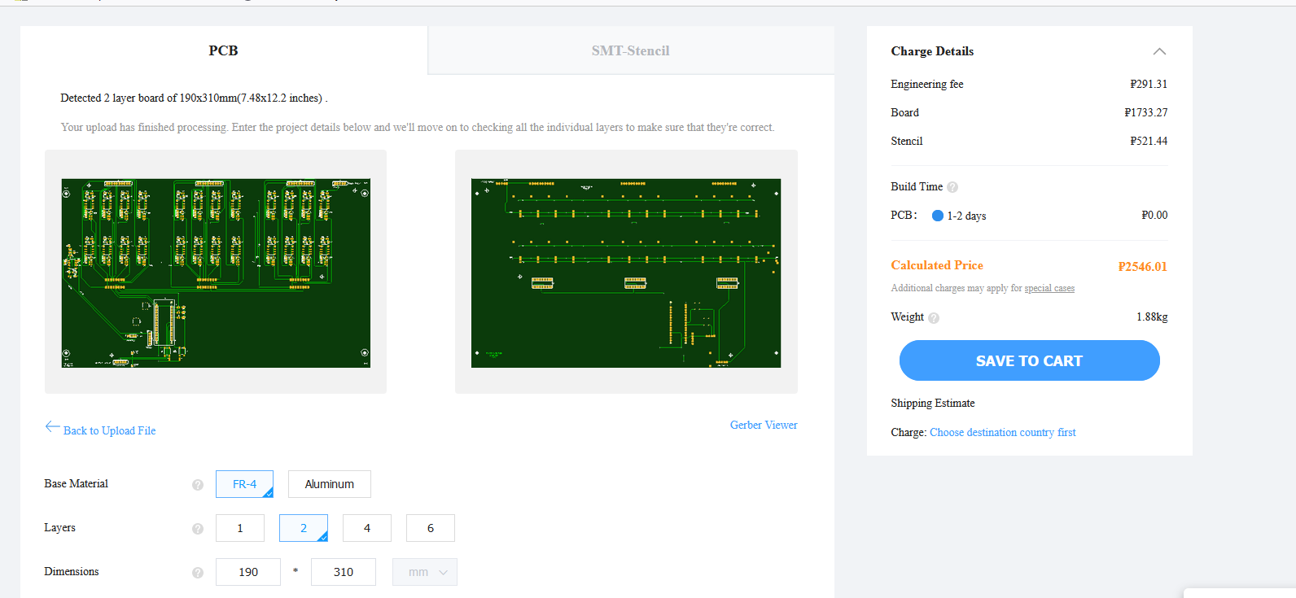
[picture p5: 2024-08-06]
stend_e3/stend_main3_stencil/~rawings/order for choise/alt_stensil.png

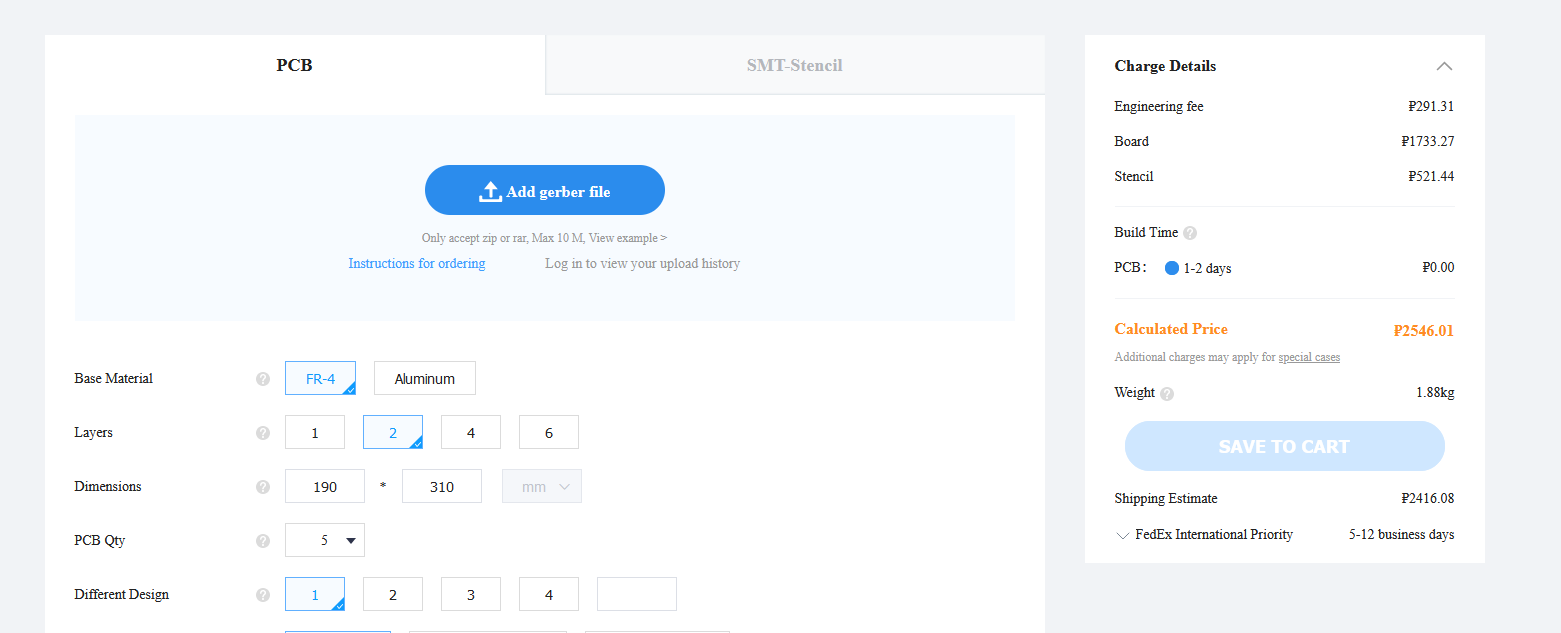
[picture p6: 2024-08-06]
stend_e3/stend_main3/~rawings/order for choise/alt_stensil_delivery.png

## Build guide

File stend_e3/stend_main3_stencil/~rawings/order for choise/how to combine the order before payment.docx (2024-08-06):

How to combine the order before payment?

1 log in your JLCPCB account. And upload your first gerber file , choose the PCB specifications.

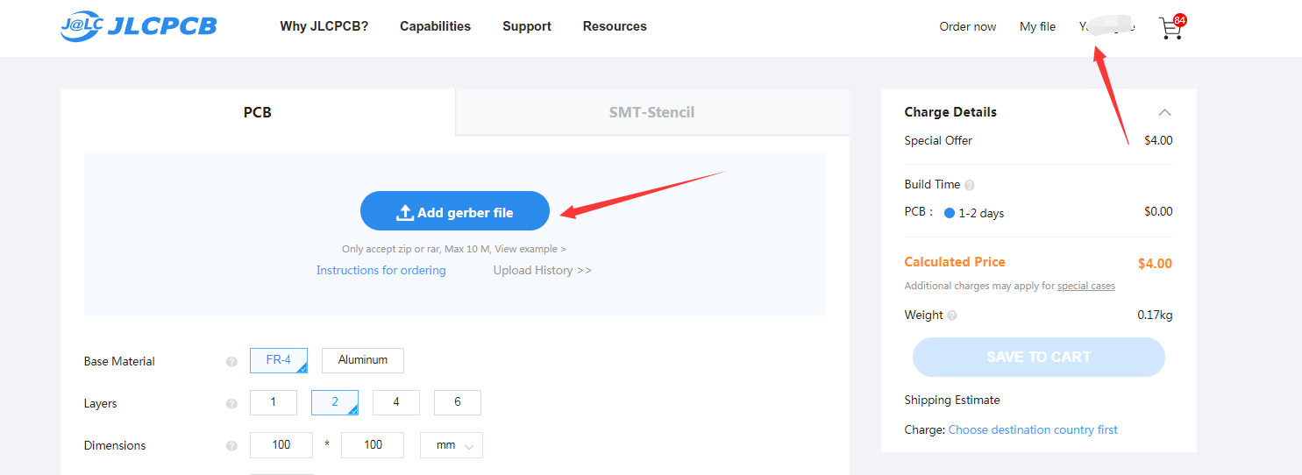
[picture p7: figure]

2, Save the order to the cart , then you will see the View cart.

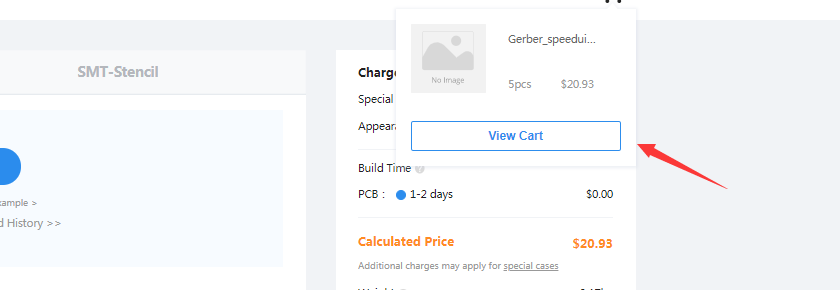
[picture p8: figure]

3, Click view cart, then find add new item button

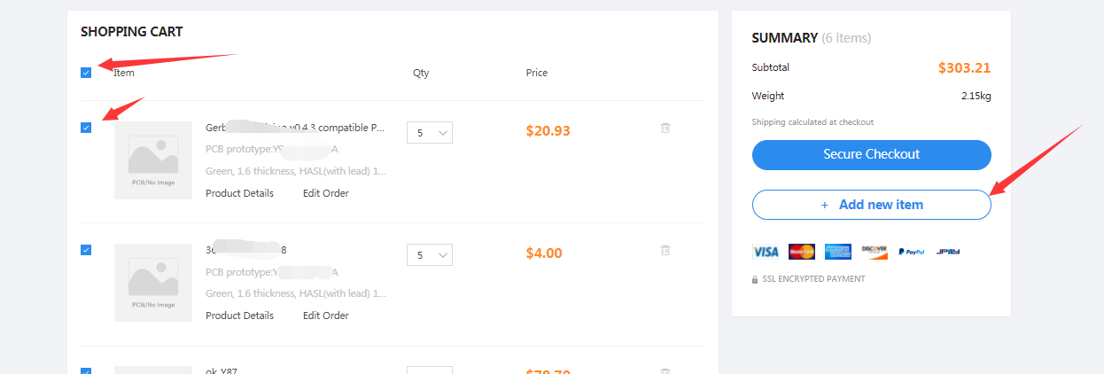
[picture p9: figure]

Then you will go back to the quote page again then you can upload the second order. If you want to combine a stencil order you can also choose the right side ,”SMT-Stencil” option.

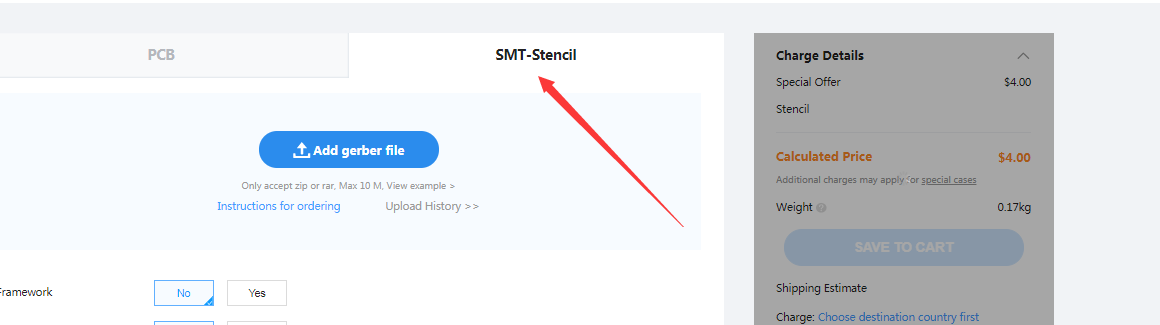
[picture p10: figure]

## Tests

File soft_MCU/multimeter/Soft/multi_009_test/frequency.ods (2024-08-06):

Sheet: Sheet3
ADC*VREF=VIN*1024
VIN=(ADC*VREF)/1024
Vref
1.1 | 0.00107421875
4.31 | 0.00420898438
5.02 | 0.00490234375
 |  | coeff
4600 | 4530 | 1.0154525386 | adt coeff
4000 | 4058 | 0.9857072449 | 300
3500 | 3600 | 0.9722222222
3000 | 3120 | 0.9615384615
2000 | 2270 | 0.8810572687
1500 | 1800 | 0.8333333333
1000 | 1350 | 0.7407407407
600 | 1000 | 0.6
 |  |  | adc coeff 0
4320 | 4130 | 1.0460048426
4050 | 3830 | 1.0574412533
3000 | 2960 | 1.0135135135
2020 | 2062 | 0.9796314258
970 | 1130 | 0.8584070796
520 | 720 | 0.7222222222
 | For 5.0 reference voltage
4970 | 4650 | 1.0688172043
 | 4500
4620 | 4373 | 1.0564829636
 | 4000
3020 | 3335 | 0.9055472264
 | 3000
2900 | 3171 | 0.9145380006
 | 2800
2700 | 2670 | 1.0112359551
 | 2400
2100 | 2130 | 0.985915493
 | 2000
1870 | 1900 | 0.9842105263
 | 1800
1670 | 1670 | 1
 | 1500
1300 | 1300 | 1
 | 1200
820 | 1000 | 0.82
 | 900
650 | 830 | 0.7831325301
 | 750
420 | 630 | 0.6666666667 |  | 419.58
 | 560
270 | 490 | 0.5510204082
 | 450
200 | 320 | 0.625
 | 300
150 | 270 | 0.5555555556
 | 180
70 | 140 | -80
 | 130
50 | 127 | -80
 | 110
20 | 100 | -80
 | 80
 | 50 | 0
 | 0
45 | 114.3
47 | 119.38
temperature calculation
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

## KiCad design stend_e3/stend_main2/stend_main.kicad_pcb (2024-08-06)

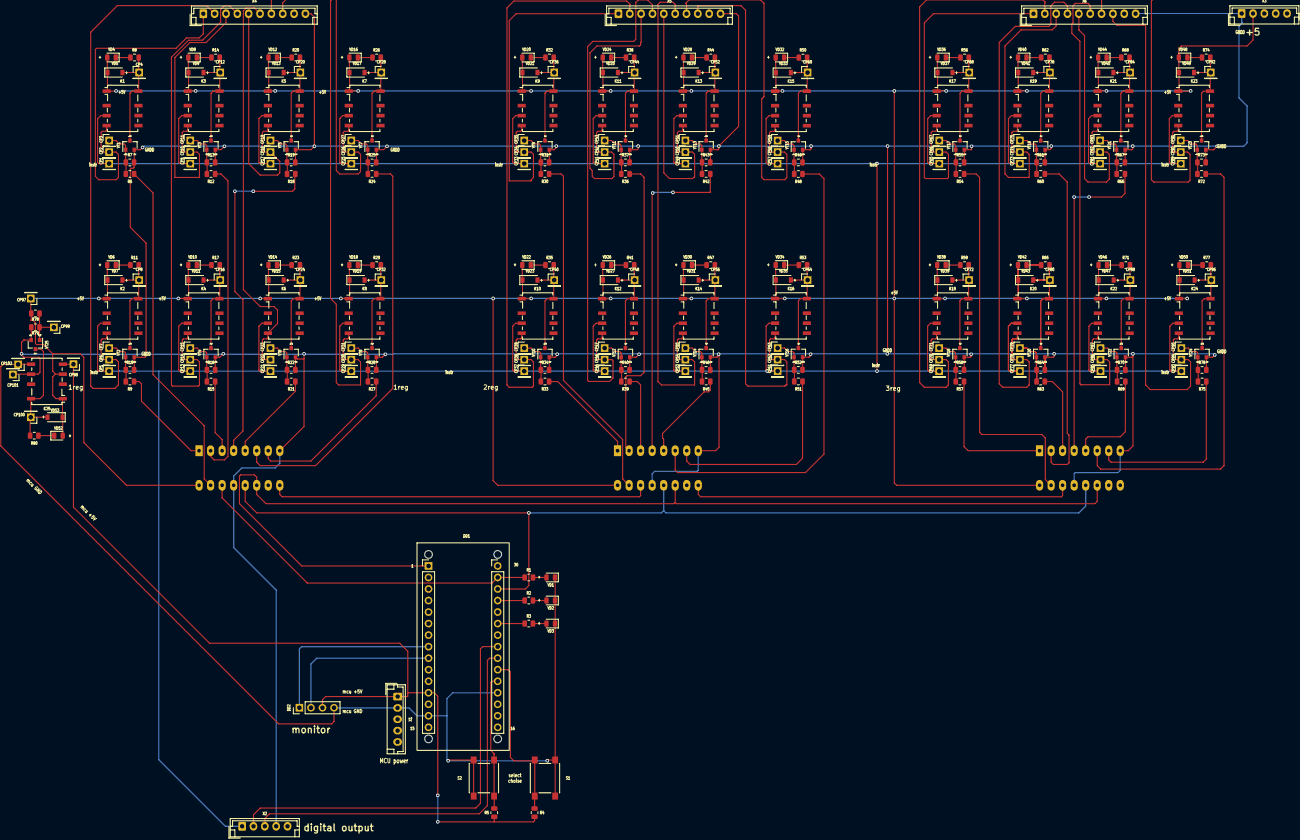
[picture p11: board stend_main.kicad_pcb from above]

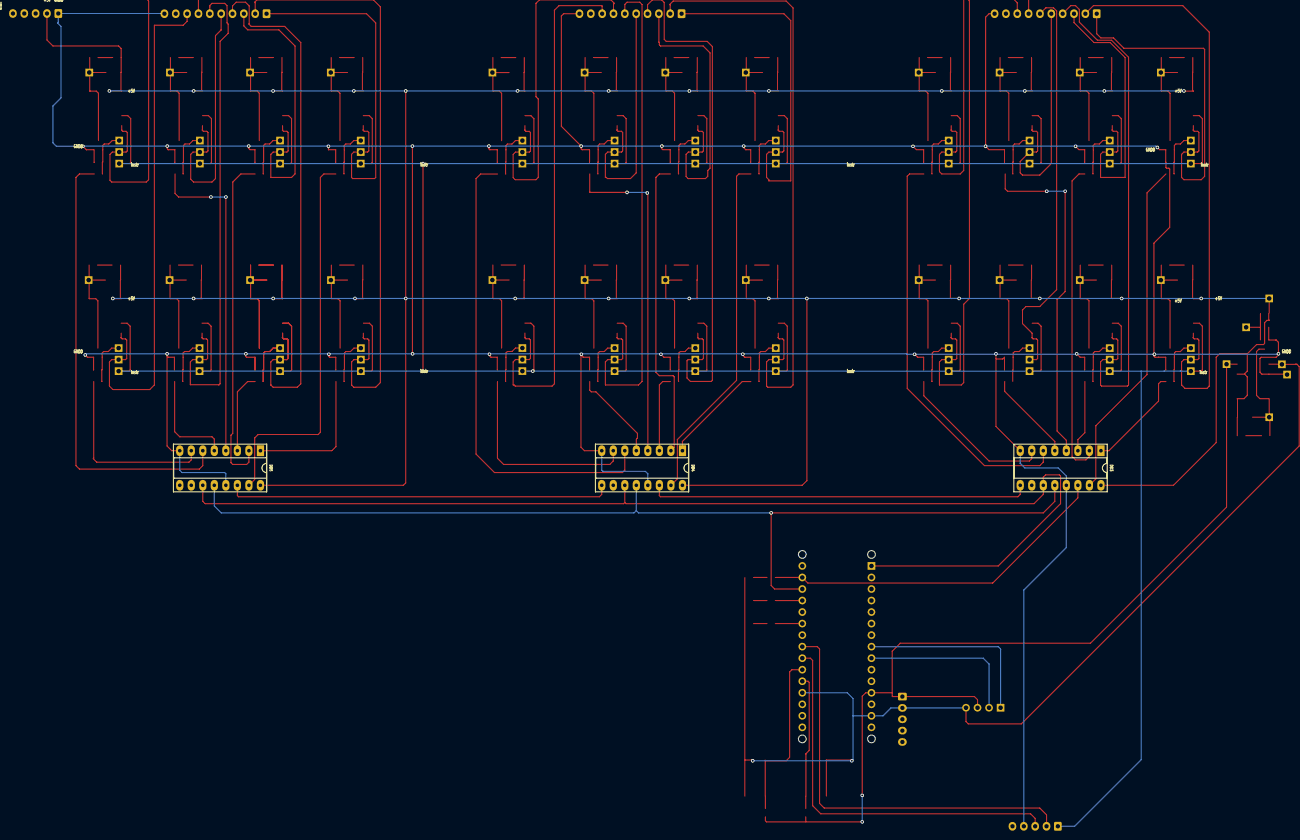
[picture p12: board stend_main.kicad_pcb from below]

Board: 2 copper layers, 298 parts (3 on the bottom side), 144 nets.

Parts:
CP1, CP2, CP3, CP5, CP6, CP7, CP9, CP10, CP11, CP13, CP14, CP15, CP17, CP18, CP19, CP21, CP22, CP23, CP25, CP26, CP27, CP29, CP30, CP31, CP33, CP34, CP35, CP37, CP38, CP39, CP41, CP42, CP43, CP45, CP46, CP47, CP49, CP50, CP51, CP53, CP54, CP55, CP57, CP58, CP59, CP61, CP62, CP63, CP65, CP66, CP67, CP69, CP70, CP71, CP73, CP74, CP75, CP77, CP78, CP79, CP81, CP82, CP83, CP85, CP86, CP87, CP89, CP90, CP91, CP93, CP94, CP95, CP97, CP98, CP99: CP_L; PinHeader_1x01_P2.54mm_Vertical
CP4, CP8, CP12, CP16, CP20, CP24, CP28, CP32, CP36, CP40, CP44, CP48, CP52, CP56, CP60, CP64, CP68, CP72, CP76, CP80, CP84, CP88, CP92, CP96, CP100, CP101, CP102: CP_R; PinHeader_1x01_P2.54mm_Vertical
DD1: NANO_ATmega328; Nano_328pu
DD2: Display_1306; PinHeader_1x04_P2.54mm_Vertical
DD3, DD4, DD5: 74HC595; DIP-16_W7.62mm_Socket_LongPads
K1, K2, K3, K4, K5, K6, K7, K8, K9, K10, K11, K12, K13, K14, K15, K16, K17, K18, K19, K20, K21, K22, K23, K24, K25: G6K-2F-Y-5VDC_L; Relay_DPDT_Omron_G6K-2F-Y
R1, R2, R3, R4, R5: 33k; R_0805_2012Metric
R6, R9, R12, R15, R18, R21, R24, R27, R30, R33, R36, R39, R42, R45, R48, R51, R54, R57, R60, R63, R66, R69, R72, R75, R78: 2.2k; R_0805_2012Metric
R7, R10, R13, R16, R19, R22, R25, R28, R31, R34, R37, R40, R43, R46, R49, R52, R55, R58, R61, R64, R67, R70, R73, R76, R79: 2.2kvert; R_0805_2012Metric
R8, R11, R14, R17, R20, R23, R26, R29, R32, R35, R38, R41, R44, R47, R50, R53, R56, R59, R62, R65, R68, R71, R74, R77, R80: 12k; R_0805_2012Metric
S1, S2: taktile button KLS7; SW_Push_2P1T_6x6mm
VD1, VD2, VD3, VD4, VD6, VD8, VD10, VD12, VD14, VD16, VD18, VD20, VD22, VD24, VD26, VD28, VD30, VD32, VD34, VD36, VD38, VD40, VD42, VD44, VD46, VD48, VD50, VD52: LED; LED_0805_2012Metric
VD5, VD7, VD9, VD11, VD13, VD15, VD17, VD19, VD21, VD23, VD25, VD27, VD29, VD31, VD33, VD35, VD37, VD39, VD41, VD43, VD45, VD47, VD49, VD51, VD53: 1N4148W; D_SOD-123
VT1, VT2, VT3, VT4, VT5, VT6, VT7, VT8, VT9, VT10, VT11, VT12, VT13, VT14, VT15, VT16, VT17, VT18, VT19, VT20, VT21, VT22, VT23, VT24, VT25: 2SC1815; SOT-23_MY_C_E_Silk
X1: JST-B2B-XHA_Left; JST_EH_B5B-EH-A_1x05_P2.50mm_Vertical
X2, X3: B5B-XH-A_Left; JST_EH_B5B-EH-A_1x05_P2.50mm_Vertical
X4, X5, X6: B10B-XH-A_right; JST_EH_B10B-EH-A_1x10_P2.50mm_Vertical

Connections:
+5V: CP97.1, DD3.16 (VCC), DD4.16 (VCC), DD5.16 (VCC), K1.1, K2.1, K3.1, K4.1, K5.1, K6.1, K7.1, K8.1, K9.1, K10.1, K11.1, K12.1, K13.1, K14.1, K15.1, K16.1, K17.1, K18.1, K19.1, K20.1, K21.1, K22.1, K23.1, K24.1, K25.1, K25.3, R78.1, VD4.2 (A), VD5.1 (K), VD6.2 (A), VD7.1 (K), VD8.2 (A), VD9.1 (K), VD10.2 (A), VD11.1 (K), VD12.2 (A), VD13.1 (K), VD14.2 (A), VD15.1 (K), VD16.2 (A), VD17.1 (K), VD18.2 (A), VD19.1 (K), VD20.2 (A), VD21.1 (K), VD22.2 (A), VD23.1 (K), VD24.2 (A), VD25.1 (K), VD26.2 (A), VD27.1 (K), VD28.2 (A), VD29.1 (K), VD30.2 (A), VD31.1 (K), VD32.2 (A), VD33.1 (K), VD34.2 (A), VD35.1 (K), VD36.2 (A), VD37.1 (K), VD38.2 (A), VD39.1 (K), VD40.2 (A), VD41.1 (K), VD42.2 (A), VD43.1 (K), VD44.2 (A), VD45.1 (K), VD46.2 (A), VD47.1 (K), VD48.2 (A), VD49.1 (K), VD50.2 (A), VD51.1 (K), VD52.2 (A), VD53.1 (K), X3.2
/2_MCU/CS/SS: DD1.28 (D10/PB2(CS/SS)), DD3.12 (RCLK), DD4.12 (RCLK), DD5.12 (RCLK)
/2_MCU/MOSI: DD1.29 (D11/PB3(MOSI)), DD3.14 (SER), R1.1
/2_MCU/SCK: DD1.1 (D13/PB5(SCK)), DD3.11 (SRCLK), DD4.11 (SRCLK), DD5.11 (SRCLK)
/2_MCU/SYNC IN: DD1.22 (D4/PD4), X2.3
/2_MCU/SYNC OUT: DD1.23 (D5/PD5), X2.2
/CTRL1: CP2.1, K1.4, X4.1
/CTRL2: CP6.1, K2.4, X4.2
/CTRL3: CP10.1, K3.4, X4.3
/CTRL4: CP14.1, K4.4, X4.4
/CTRL5: CP18.1, K5.4, X4.5
/CTRL6: CP22.1, K6.4, X4.6
/CTRL7: CP26.1, K7.4, X4.7
/CTRL8: CP30.1, K8.4, X4.8
/CTRL9: CP34.1, K9.4, X5.1
/CTRL10: CP38.1, K10.4, X5.2
/CTRL11: CP42.1, K11.4, X5.3
/CTRL12: CP46.1, K12.4, X5.4
/CTRL13: CP50.1, K13.4, X5.5
/CTRL14: CP54.1, K14.4, X5.6
/CTRL15: CP58.1, K15.4, X5.7
/CTRL16: CP62.1, K16.4, X5.8
/CTRL17: CP66.1, K17.4, X6.1
/CTRL18: CP70.1, K18.4, X6.2
/CTRL19: CP74.1, K19.4, X6.3
/CTRL20: CP78.1, K20.4, X6.4
/CTRL21: CP82.1, K21.4, X6.5
/CTRL22: CP86.1, K22.4, X6.6
/CTRL23: CP90.1, K23.4, X6.7
/CTRL24: CP94.1, K24.4, X6.8
/INSTR+: CP1.1, CP5.1, CP9.1, CP13.1, CP17.1, CP21.1, CP25.1, CP29.1, CP33.1, CP37.1, CP41.1, CP45.1, CP49.1, CP53.1, CP57.1, CP61.1, CP65.1, CP69.1, CP73.1, CP77.1, CP81.1, CP85.1, CP89.1, CP93.1, K1.3, K2.3, K3.3, K4.3, K5.3, K6.3, K7.3, K8.3, K9.3, K10.3, K11.3, K12.3, K13.3, K14.3, K15.3, K16.3, K17.3, K18.3, K19.3, K20.3, K21.3, K22.3, K23.3, K24.3, X2.1
/MCU+: CP98.1, DD1.12 (+5V), DD2.3 (VCC), K25.4, R4.2, R5.1, X1.1
/MCU_GND: CP102.1, DD1.14 (GND), DD1.19 (GND), DD2.4 (GND), K25.5, S1.2, S2.2, VD1.1 (K), VD2.1 (K), VD3.1 (K), X1.2
/RL1: DD3.15 (QA), R6.1
/RL2: DD3.1 (QB), R9.1
/RL3: DD3.2 (QC), R12.1
/RL4: DD3.3 (QD), R15.1
/RL5: DD3.4 (QE), R18.1
/RL6: DD3.5 (QF), R21.1
/RL7: DD3.6 (QG), R24.1
/RL8: DD3.7 (QH), R27.1
/RL9: DD4.15 (QA), R30.1
/RL10: DD4.1 (QB), R33.1
/RL11: DD4.2 (QC), R36.1
/RL12: DD4.3 (QD), R39.1
/RL13: DD4.4 (QE), R42.1
/RL14: DD4.5 (QF), R45.1
/RL15: DD4.6 (QG), R48.1
/RL16: DD4.7 (QH), R51.1
/RL17: DD5.15 (QA), R54.1
/RL18: DD5.1 (QB), R57.1
/RL19: DD5.2 (QC), R60.1
/RL20: DD5.3 (QD), R63.1
/RL21: DD5.4 (QE), R66.1
/RL22: DD5.5 (QF), R69.1
/RL23: DD5.6 (QG), R72.1
/RL24: DD5.7 (QH), R75.1
GNDD: CP101.1, DD3.8 (GND), DD3.13 (~OE), DD4.8 (GND), DD4.13 (~OE), DD5.8 (GND), DD5.13 (~OE), K25.6, R7.2, R10.2, R13.2, R16.2, R19.2, R22.2, R25.2, R28.2, R31.2, R34.2, R37.2, R40.2, R43.2, R46.2, R49.2, R52.2, R55.2, R58.2, R61.2, R64.2, R67.2, R70.2, R73.2, R76.2, R79.2, VT1.2 (E), VT2.2 (E), VT3.2 (E), VT4.2 (E), VT5.2 (E), VT6.2 (E), VT7.2 (E), VT8.2 (E), VT9.2 (E), VT10.2 (E), VT11.2 (E), VT12.2 (E), VT13.2 (E), VT14.2 (E), VT15.2 (E), VT16.2 (E), VT17.2 (E), VT18.2 (E), VT19.2 (E), VT20.2 (E), VT21.2 (E), VT22.2 (E), VT23.2 (E), VT24.2 (E), VT25.2 (E), X2.4, X2.5, X3.1, X4.10, X5.10, X6.10
unnamed: CP3.1, R6.2, R7.1, VT1.1 (B)
unnamed: CP4.1, K1.8, R8.2, VD5.2 (A), VT1.3 (C)
unnamed: CP7.1, R9.2, R10.1, VT2.1 (B)
unnamed: CP8.1, K2.8, R11.2, VD7.2 (A), VT2.3 (C)
unnamed: CP11.1, R12.2, R13.1, VT3.1 (B)
unnamed: CP12.1, K3.8, R14.2, VD9.2 (A), VT3.3 (C)
unnamed: CP15.1, R15.2, R16.1, VT4.1 (B)
unnamed: CP16.1, K4.8, R17.2, VD11.2 (A), VT4.3 (C)
unnamed: CP19.1, R18.2, R19.1, VT5.1 (B)
unnamed: CP20.1, K5.8, R20.2, VD13.2 (A), VT5.3 (C)
unnamed: CP23.1, R21.2, R22.1, VT6.1 (B)
unnamed: CP24.1, K6.8, R23.2, VD15.2 (A), VT6.3 (C)
unnamed: CP27.1, R24.2, R25.1, VT7.1 (B)
unnamed: CP28.1, K7.8, R26.2, VD17.2 (A), VT7.3 (C)
unnamed: CP31.1, R27.2, R28.1, VT8.1 (B)
unnamed: CP32.1, K8.8, R29.2, VD19.2 (A), VT8.3 (C)
unnamed: CP35.1, R30.2, R31.1, VT9.1 (B)
unnamed: CP36.1, K9.8, R32.2, VD21.2 (A), VT9.3 (C)
unnamed: CP39.1, R33.2, R34.1, VT10.1 (B)
unnamed: CP40.1, K10.8, R35.2, VD23.2 (A), VT10.3 (C)
unnamed: CP43.1, R36.2, R37.1, VT11.1 (B)
unnamed: CP44.1, K11.8, R38.2, VD25.2 (A), VT11.3 (C)
unnamed: CP47.1, R39.2, R40.1, VT12.1 (B)
unnamed: CP48.1, K12.8, R41.2, VD27.2 (A), VT12.3 (C)
unnamed: CP51.1, R42.2, R43.1, VT13.1 (B)
unnamed: CP52.1, K13.8, R44.2, VD29.2 (A), VT13.3 (C)
unnamed: CP55.1, R45.2, R46.1, VT14.1 (B)
unnamed: CP56.1, K14.8, R47.2, VD31.2 (A), VT14.3 (C)
unnamed: CP59.1, R48.2, R49.1, VT15.1 (B)
unnamed: CP60.1, K15.8, R50.2, VD33.2 (A), VT15.3 (C)
unnamed: CP63.1, R51.2, R52.1, VT16.1 (B)
unnamed: CP64.1, K16.8, R53.2, VD35.2 (A), VT16.3 (C)
unnamed: CP67.1, R54.2, R55.1, VT17.1 (B)
unnamed: CP68.1, K17.8, R56.2, VD37.2 (A), VT17.3 (C)
unnamed: CP71.1, R57.2, R58.1, VT18.1 (B)
unnamed: CP72.1, K18.8, R59.2, VD39.2 (A), VT18.3 (C)
unnamed: CP75.1, R60.2, R61.1, VT19.1 (B)
unnamed: CP76.1, K19.8, R62.2, VD41.2 (A), VT19.3 (C)
unnamed: CP79.1, R63.2, R64.1, VT20.1 (B)
unnamed: CP80.1, K20.8, R65.2, VD43.2 (A), VT20.3 (C)
unnamed: CP83.1, R66.2, R67.1, VT21.1 (B)
unnamed: CP84.1, K21.8, R68.2, VD45.2 (A), VT21.3 (C)
unnamed: CP87.1, R69.2, R70.1, VT22.1 (B)
unnamed: CP88.1, K22.8, R71.2, VD47.2 (A), VT22.3 (C)
unnamed: CP91.1, R72.2, R73.1, VT23.1 (B)
unnamed: CP92.1, K23.8, R74.2, VD49.2 (A), VT23.3 (C)
unnamed: CP95.1, R75.2, R76.1, VT24.1 (B)
unnamed: CP96.1, K24.8, R77.2, VD51.2 (A), VT24.3 (C)
unnamed: CP99.1, R78.2, R79.1, VT25.1 (B)
unnamed: CP100.1, K25.8, R80.2, VD53.2 (A), VT25.3 (C)
unnamed: DD1.8 (A4/PC4), DD2.1 (SDA)
unnamed: DD1.9 (A5/PC5), DD2.2 (SCL)
unnamed: DD1.20 (D2/PD2), R5.2, S2.1
unnamed: DD1.21 (D3/PD3), R4.1, S1.1
unnamed: DD1.25 (D7/PD7), R3.1
unnamed: DD1.27 (D9/PB1), R2.1
unnamed: DD3.9 (QH'), DD4.14 (SER)
unnamed: DD4.9 (QH'), DD5.14 (SER)
unnamed: R1.2, VD1.2 (A)
unnamed: R2.2, VD2.2 (A)
unnamed: R3.2, VD3.2 (A)
unnamed: R8.1, VD4.1 (K)
unnamed: R11.1, VD6.1 (K)
unnamed: R14.1, VD8.1 (K)
unnamed: R17.1, VD10.1 (K)
unnamed: R20.1, VD12.1 (K)
unnamed: R23.1, VD14.1 (K)
unnamed: R26.1, VD16.1 (K)
unnamed: R29.1, VD18.1 (K)
unnamed: R32.1, VD20.1 (K)
unnamed: R35.1, VD22.1 (K)
unnamed: R38.1, VD24.1 (K)
unnamed: R41.1, VD26.1 (K)
unnamed: R44.1, VD28.1 (K)
unnamed: R47.1, VD30.1 (K)
unnamed: R50.1, VD32.1 (K)
unnamed: R53.1, VD34.1 (K)
unnamed: R56.1, VD36.1 (K)
unnamed: R59.1, VD38.1 (K)
unnamed: R62.1, VD40.1 (K)
unnamed: R65.1, VD42.1 (K)
unnamed: R68.1, VD44.1 (K)
unnamed: R71.1, VD46.1 (K)
unnamed: R74.1, VD48.1 (K)
unnamed: R77.1, VD50.1 (K)
unnamed: R80.1, VD52.1 (K)

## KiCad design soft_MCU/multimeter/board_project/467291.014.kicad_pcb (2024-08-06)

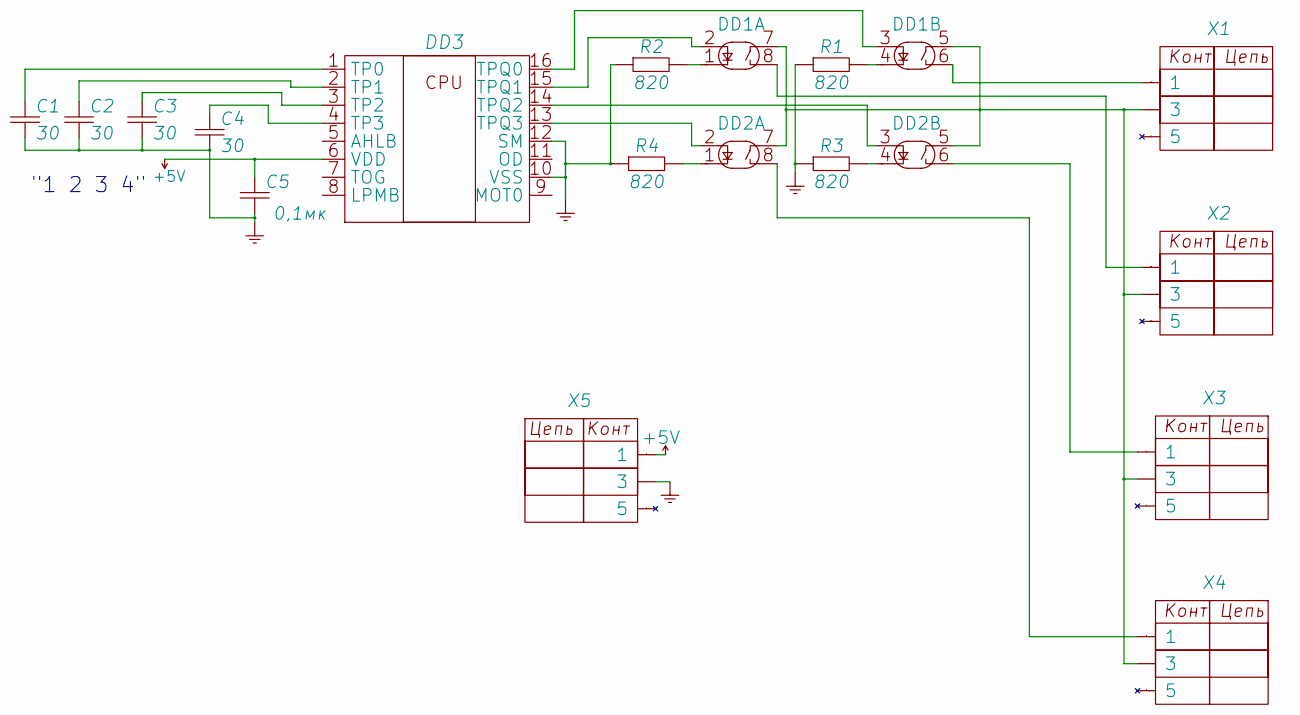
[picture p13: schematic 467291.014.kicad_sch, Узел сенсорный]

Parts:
C1, C2, C3, C4: K10-69v-MP0-50V-2012M-30pF-10%-[LTM][Capacitors][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; [LTM][C][0805][2012M]
C5: K10-69v-N90-25V-2012M-0,1uF+80-20%-[LTM][Capacito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; [LTM][C][0805][2012M]
DD1, DD2: kR293KP3AT-Isolator; DIP-8_W8.89mm_SMDSocket_LongPads
DD3: kikadtest1-cache_TP224_Sensor-kikadtest1-cache; HTSSOP-16-1EP_4x5mm
R1, R2, R3, R4: R1-12-0,125-820Ohm-5%-M-[LTM][Resistors][R112][08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; [LTM][R][0805][2012M]
X1, X2, X3, X4: snp346-5RP21-1_3cont-[LTM][Connectors][СНП346][5]; button_sensor_18mm
X5: snp346-5RP21-1_3cont-[LTM][Connectors][СНП346][5]; button_1x3_P5mm_Vert_longHoles

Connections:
+5V: C5.2, DD3.6 (VDD), X5.1
unnamed: C1.2, DD3.1 (TP0)
unnamed: C2.2, DD3.2 (TP1)
unnamed: C3.2, DD3.3 (TP2)
unnamed: C4.2, DD3.4 (TP3)
unnamed: DD1.1, R2.2
unnamed: DD1.2, DD3.15 (TPQ1)
unnamed: DD1.3, DD3.16 (TPQ0)
unnamed: DD1.4, R1.2
unnamed: DD1.5, DD1.7, DD2.5, DD2.7, X1.3, X2.3, X3.3, X4.3
unnamed: DD1.6, X1.1
unnamed: DD1.8, X2.1
unnamed: DD2.1, R4.2
unnamed: DD2.2, DD3.13 (TPQ3)
unnamed: DD2.3, DD3.14 (TPQ2)
unnamed: DD2.4, R3.2
unnamed: DD2.6, X3.1
unnamed: DD2.8, X4.1

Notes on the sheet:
"1 2 3 4"

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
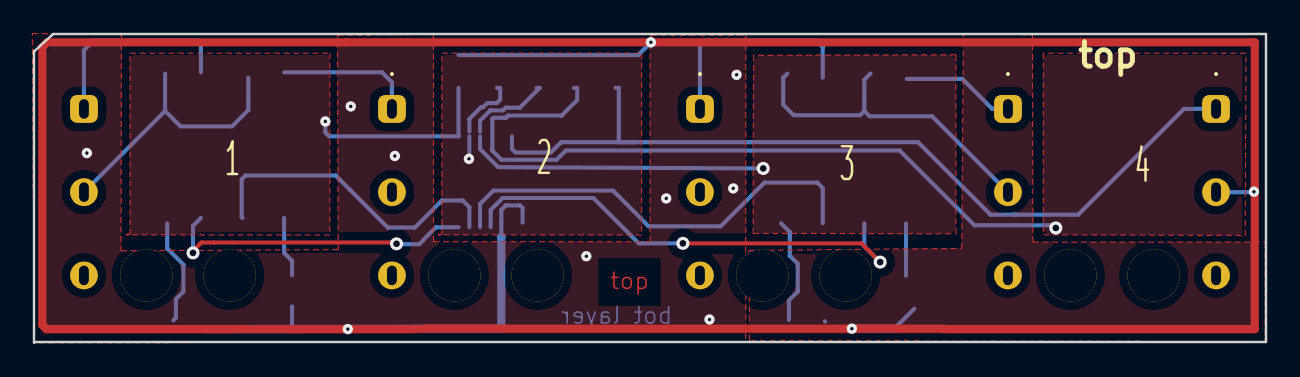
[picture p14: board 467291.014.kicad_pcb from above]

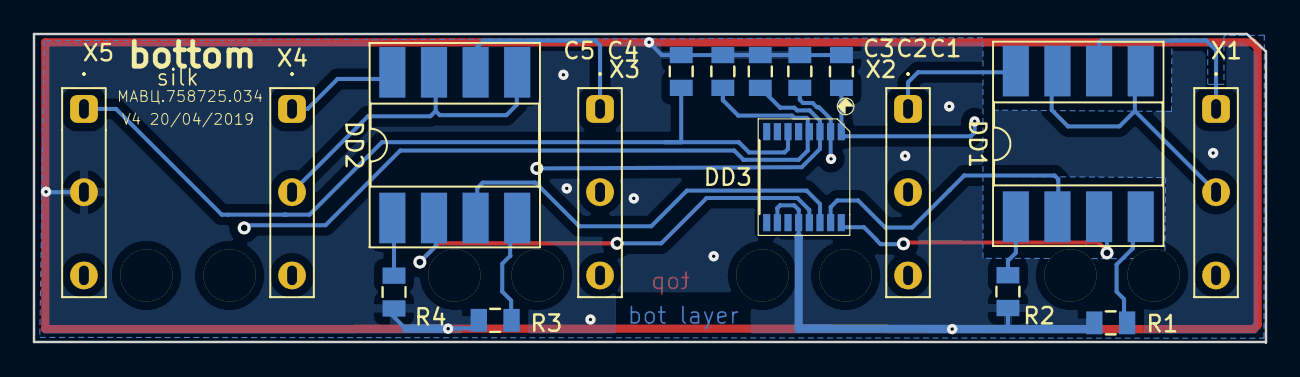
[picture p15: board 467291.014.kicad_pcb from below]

Board: 32 copper layers, 75.2 x 18.8 mm, 17 parts (17 on the bottom side), 19 nets.

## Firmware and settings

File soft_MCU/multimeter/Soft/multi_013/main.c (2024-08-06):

/*
 * ol_328.c
 *
 * Created: 2/19/2020 2:24:59 PM
 * Author : john
 th*/ 
/*
v.013 24 Oct 2021
add shift register initialization  void ShiftRegReset(void), removed display output in this routine (uncomment if need)
add initialization ShiftRegReset into shiftregister1 and shiftregister2											

in13.1 version will be final for use, start after resetting.


v.012 15 Oct 2021

insert argument in shiftregister1

v011_test 14 Oct

set properly timing for measurements
and dual loading
in main will work for without display dummy
in routine work for display dummy

v.010_test_new_pulsing 22/09/2021

create pulses in main and  it will be push to the register

create pulse for voltmeter measure enable for ext trig input on D4 port

v.009_test 22/09/2021
add controller operational testing section



v.008 17/09/2021
will start to add register controls
attempt number output (1-9)

v.007 14/09/2021

will remove unused variables
banner changed to 007

multi v.006 14/12/2020
make reference voltage source 5V, this is used when no programming mode. For work must be 
!!!!!switched off USB from PC!!!!!
otherwise it will not be 5 V and can be overheated

- recalculate reference voltage from 4.3V 2 5.0V
- rearrange table voltages coefficient



multi v.005 11/12/2020
-make temperature measuring by scaling  the measured temperature voltage
 and find it relevance in the voltage table, 
 then find  the temperature cell with same cell number in temperature table
 - make temperature output as sign, temp value, and termoresistor current value (calculated)
 
multi v.004 09/12/2020 
remove garbage after poweroff in menu and stopwatch


multi v.003 07/12/2020
- make relevance between voltage temperature table and temperature table
- make consolidated output temperature and voltage 



multi v.002
- ADC & ADT  was multiplied to coeff, the difference between one chip voltmeter is about 50 mV
- create temperature table
-make output temperature table from -10 to +40C
multi_v001

try to make ADC with ref is Vcc 
count coeff make for precise measuring

multi_v000
started multimeter project. the last demo project will be 2.6.11
in which works voltage meter.
will be created Temperature measuring
later will be finished distance meter
it has measured by 1.1 ref voltage ADC

but not measured ADT - the ref voltage is less, then on ADT pin (2.2 V)

ol_328_2.6_11   26/11/2020
try to convert float 2 string

//------------------------------------------------------------
!!!!!!!!!!make measuring cycle from 0 to 0.9 v in mV!!!!!!!
//------------------------------------------------------------
measured first 2 digits as 957 mV multimeter and 9559 on MCU

ol_328_2.6_10 24/11/2020
now  i will try to setting ADC
and can output integer number  as 29523 (take in mind, that integer must be less, than 31625)


2.6.09 23/11/2020
changed point RDA to ADC and  corrected   readarray1  output 

2.6.08
insert watchdog timer,timer off,the last stable version
2.6.07
the jumping over items corrected
2.6.06
Stable version , just stopwatch jumps from 8 to 0. Need correct 9
2.6.05
almost  repaired stopwatch (seconds and minutes)
2.6.04
repaired menu and arrow.
stopwatch don't work.
2.6.03
failed, but have 2bytes variable output
5.04.2020
v.2.6.02
-work menu
-stopwatch
-creating the PWM timer for ultrasonic measurement. (TCNT2)
Program Memory Usage 	:	4110 bytes   12.5 % Full
Data Memory Usage 		:	489 bytes   23.9 %
25/03/2020
v:2:6:01
total 6796 program 2410 data 383
banner print from buffer, register name print from buffer
seconds properly counts, the places for stop watch digits are improved.
work to create regiter value to out - partially solved, but not yet.
24/03/2020
v.2.6.00
total 5336 program 1888 data 365
banner improved 
23/03/2020
v.2.5
total 5246 program 1800 data 365 (in next version will be added watch, big letters and y = sin X)
output improved, decreased arrays small letters and big letters to free RAM.
later must be drop to progmem. the version bunner added to right down corner.
The weekdays print by downstairs.
20/03/20/20
v.2.4
- output in any string and any columns, the function parameters
	can be loaded as variables, as constant, and can be loaded in decimal format.(binary and hexadecimal too, but decimal is more simple
	to provide SetPgAddr  prompt string or column number)
- loaded text to buffer and output from buffer by Char1 function.
- loaded self made fonts bigger than 8x6
16/03/2020
v.2.3
12/03/2020
v/2/1
change blink functions arguments - decrease number blink functions from 15 2 3.
06/03/2020
v.2.1
has been add the symbols function from massive font
04/03/2020
v.2.0 has been wrote display on and off and writing commands and symbols
has been add the clearscreen, renderscreen, reset, and 0 and 4 output
26/02/2020
write i2c functions

02/22/2020
the progam for the  ATMEGA_328   AND twi 1306 oled display
the address 0x78
THERE HAS WRITTEN the signalling code for blinking only by red green and yellow LEDs

*/

// --------------------made from source end ----------------------------------
#include "main.h"
#include "adc.h"
#include "adt.h"


//----------------gLOBAL VARIABLES---------------------------
unsigned char data =  0xAF;
/*char a;char b;*/
//int n=0;
int m=20;
float p2;
int t=20;

unsigned char n=1;
//----------defines
#define START		0x08			// A START condition has been transmitted; bit 0: timeout start-condition
#define SLA_W       0x78		//for write 0 bit isn't set, so it will be just addr. only 0x78 0x7A
#define MT_SLA_ACK  0x18            //mt slave addr acknol ;SLA+W has been transmitted; ACK has been received
#define DATA		0x22			//22 is for sample only it must be command or data	later
#define MT_DATA_ACK 0x28			//Data byte has been transmitted;ACK has been received
// --------------------------------------------
void Adc (void);
void Adt (void);
void Adt1 (void);
void Arrow (void);
void Banner (void);
void Bannercenter (void);
void Blink_red_n (unsigned char n);
void Blink_yellow_n(unsigned char n);
void Blink_green_n(unsigned char n);
void Blink_13 (unsigned char n);
void Buttons (void);
void Byt2Bit (unsigned char a0);
void Byt2Bit22 (unsigned char a0);
void ERROR1(void);
void ERROR2(void);
void ERROR3(void);
void I2C_Start(void);
void I2C_SLA_W(void);
void I2C_cnt_COM (void);
void I2C_cnt_DATA (void);
void I2C_cnt_DATA_all (void);
void I2C_DATA (void);
/*void (TIMER1_COMPA_vect)(void);*/
void I2C_Stop (void);
void init_PWM_timer(void);
void init_Echo_pin (void);
void Reset(void);
void Char1(unsigned char a);
void Char25x32 (void);
void Clearscreen(void);
void Coeff(float p2);
void MeasurementEnable(void);
void Menu (void);
void MenuPrint (void);
void MenuOut (void);
void port_ini_Adc(void);
void port_ini(void);
void ReadArray (void);
void ReadArray1 (void);
void Reg0_out (void);
void Reg1_out (void);
void Reg2_out (void);
void Reg3_out (void);
void Reg4_out (void);
void Reg5_out (void);
void Reg6_out (void);
void Reg7_out (void);
void RegisterPrint (void);
void Renderscreen(void);
void SetPgAddr(unsigned char PgPosSt,unsigned char PgPosEnd);
// void SetPgAddr1(unsigned char PgPosSt,unsigned char PgPosEnd);
void SetClmAddr(unsigned char ColPosSt, unsigned char ColPosEnd);
// void SetClmAddr1(unsigned char ColPosSt, unsigned char ColPosEnd);
void StopWatch (void);

void Charn(void);
//void TempCalc(unsigned int tempVoltage,unsigned int temp);
void ShiftRegister(void);void ShiftRegReset(void);
void ShiftRegister1(unsigned char n);void ShiftRegister2(unsigned char n);
void TempCalc(void);
void TestPortDC (void);
void TestPortD_B (void);
void Timer (void);
void timer_ini(void);
void timer_10us (void);
void timer_10us_ini (void);
void VoltTempCalc(void);
void VoltTempCalc1(int p4);
// ---------------------------------------------
// unsigned char font8x6[50][6] = {
// 	{0x00, 0x00, 0x00, 0x00, 0x00, 0x00}, // sp 0    (shift +32)
// 	{0x00, 0x00, 0x00, 0x2f, 0x00, 0x00}, // !  1		
// 	{0x00, 0x00, 0x07, 0x00, 0x07, 0x00}, // "	2
// 	{0x00, 0x14, 0x7f, 0x14, 0x7f, 0x14}, // #	3
// 	{0x00, 0x24, 0x2a, 0x7f, 0x2a, 0x12}, // $	4
// 	{0x00, 0x62, 0x64, 0x08, 0x13, 0x23}, // %	5
// 	{0x00, 0x36, 0x49, 0x55, 0x22, 0x50}, // &	6
// 	{0x00, 0x00, 0x05, 0x03, 0x00, 0x00}, // '	7
// 	{0x00, 0x00, 0x1c, 0x22, 0x41, 0x00}, // (	8	
// 	{0x00, 0x00, 0x41, 0x22, 0x1c, 0x00}, // )	9
// 	{0x00, 0x14, 0x08, 0x3E, 0x08, 0x14}, // *	10
// 	{0x00, 0x08, 0x08, 0x3E, 0x08, 0x08}, // +	11
// 	{0x00, 0x00, 0x00, 0xA0, 0x60, 0x00}, // ,	12
// 	{0x00, 0x08, 0x08, 0x08, 0x08, 0x08}, // -	13
// 	{0x00, 0x00, 0x60, 0x60, 0x00, 0x00}, // .	14
// 	{0x00, 0x20, 0x10, 0x08, 0x04, 0x02}, // /	15
//	{0x00, 0x3E, 0x51, 0x49, 0x45, 0x3E}, // 0	16    ascii 48
// 	{0x00, 0x00, 0x42, 0x7F, 0x40, 0x00}, // 1	17
// 	{0x00, 0x42, 0x61, 0x51, 0x49, 0x46}, // 2	18
// 	{0x00, 0x21, 0x41, 0x45, 0x4B, 0x31}, // 3	19
// 	{0x00, 0x18, 0x14, 0x12, 0x7F, 0x10}, // 4	20
// 	{0x00, 0x27, 0x45, 0x45, 0x45, 0x39}, // 5	21
// 	{0x00, 0x3C, 0x4A, 0x49, 0x49, 0x30}, // 6	22
// 	{0x00, 0x01, 0x71, 0x09, 0x05, 0x03}, // 7	23     ascii 55
// 	{0x00, 0x36, 0x49, 0x49, 0x49, 0x36}, // 8	24
// 	{0x00, 0x06, 0x49, 0x49, 0x29, 0x1E}, // 9	25
// 	{0x00, 0x00, 0x36, 0x36, 0x00, 0x00}, // :  26
// 	{0x00, 0x00, 0x56, 0x36, 0x00, 0x00}, // ;  27
// 	{0x00, 0x08, 0x14, 0x22, 0x41, 0x00}, // <  28
// 	{0x00, 0x14, 0x14, 0x14, 0x14, 0x14}, // =  29
// 	{0x00, 0x00, 0x41, 0x22, 0x14, 0x08}, // >  30
// 	{0x00, 0x02, 0x01, 0x51, 0x09, 0x06}, // ?	31
// 	{0x00, 0x32, 0x49, 0x59, 0x51, 0x3E}, // @	32	 ascii 64
// 	{0x00, 0x7C, 0x12, 0x11, 0x12, 0x7C}, // A	33
// 	{0x00, 0x7F, 0x49, 0x49, 0x49, 0x36}, // B	34
// 	{0x00, 0x3E, 0x41, 0x41, 0x41, 0x22}, // C	35
// 	{0x00, 0x7F, 0x41, 0x41, 0x22, 0x1C}, // D	36
// 	{0x00, 0x7F, 0x49, 0x49, 0x49, 0x41}, // E	37
// 	{0x00, 0x7F, 0x09, 0x09, 0x09, 0x01}, // F	38
// 	{0x00, 0x3E, 0x41, 0x49, 0x49, 0x7A}, // G	39
// 	{0x00, 0x7F, 0x08, 0x08, 0x08, 0x7F}, // H	40
// 	{0x00, 0x00, 0x41, 0x7F, 0x41, 0x00}, // I	41
// 	{0x00, 0x20, 0x40, 0x41, 0x3F, 0x01}, // J	42
// 	{0x00, 0x7F, 0x08, 0x14, 0x22, 0x41}, // K	43	
// 	{0x00, 0x7F, 0x40, 0x40, 0x40, 0x40}, // L  44
// 	{0x00, 0x7F, 0x02, 0x0C, 0x02, 0x7F}, // M	45
// 	{0x00, 0x7F, 0x04, 0x08, 0x10, 0x7F}, // N	46
// 	{0x00, 0x3E, 0x41, 0x41, 0x41, 0x3E}, // O	47     ascii  79
// 	{0x00, 0x7F, 0x09, 0x09, 0x09, 0x06}, // P	48
// 	{0x00, 0x3E, 0x41, 0x51, 0x21, 0x5E}, // Q	49
// 	{0x00, 0x7F, 0x09, 0x19, 0x29, 0x46}, // R	50
// 	{0x00, 0x46, 0x49, 0x49, 0x49, 0x31}, // S	51
// 	{0x00, 0x01, 0x01, 0x7F, 0x01, 0x01}, // T	52
// 	{0x00, 0x3F, 0x40, 0x40, 0x40, 0x3F}, // U	53
// 	{0x00, 0x1F, 0x20, 0x40, 0x20, 0x1F}, // V	54
// 	{0x00, 0x3F, 0x40, 0x38, 0x40, 0x3F}, // W	55
// 	{0x00, 0x63, 0x14, 0x08, 0x14, 0x63}, // X	56
// 	{0x00, 0x07, 0x08, 0x70, 0x08, 0x07}, // Y	57
// 	{0x00, 0x61, 0x51, 0x49, 0x45, 0x43}, // Z	58
// 	{0x00, 0x00, 0x7F, 0x41, 0x41, 0x00}, // [	59
// 	{0x00, 0x55, 0x2A, 0x55, 0x2A, 0x55}, // backslash 60  ascii 92
// 	{0x00, 0x00, 0x41, 0x41, 0x7F, 0x00}, // ]	61
// 	{0x00, 0x04, 0x02, 0x01, 0x02, 0x04}, // ^	62
// 	{0x00, 0x40, 0x40, 0x40, 0x40, 0x40}, // _	63
// 	{0x00, 0x00, 0x01, 0x02, 0x04, 0x00}, // '	64
// 	{0x00, 0x20, 0x54, 0x54, 0x54, 0x78}, // a	65
// 	{0x00, 0x7F, 0x48, 0x44, 0x44, 0x38}, // b	66
// 	{0x00, 0x38, 0x44, 0x44, 0x44, 0x20}, // c	67
// 	{0x00, 0x38, 0x44, 0x44, 0x48, 0x7F}, // d	68
// 	{0x00, 0x38, 0x54, 0x54, 0x54, 0x18}, // e	69
// 	{0x00, 0x08, 0x7E, 0x09, 0x01, 0x02}, // f	70
// 	{0x00, 0x18, 0xA4, 0xA4, 0xA4, 0x7C}, // g	71
// 	{0x00, 0x7F, 0x08, 0x04, 0x04, 0x78}, // h	72
// 	{0x00, 0x00, 0x44, 0x7D, 0x40, 0x00}, // i	73
// 	{0x00, 0x40, 0x80, 0x84, 0x7D, 0x00}, // j	74
// 	{0x00, 0x7F, 0x10, 0x28, 0x44, 0x00}, // k	75
// 	{0x00, 0x00, 0x41, 0x7F, 0x40, 0x00}, // l	76
// 	{0x00, 0x7C, 0x04, 0x18, 0x04, 0x78}, // m	77
// 	{0x00, 0x7C, 0x08, 0x04, 0x04, 0x78}, // n	78
// 	{0x00, 0x38, 0x44, 0x44, 0x44, 0x38}, // o	79
// 	{0x00, 0xFC, 0x24, 0x24, 0x24, 0x18}, // p	80  ascii 112
// 	{0x00, 0x18, 0x24, 0x24, 0x18, 0xFC}, // q	81
// 	{0x00, 0x7C, 0x08, 0x04, 0x04, 0x08}, // r	82
// 	{0x00, 0x48, 0x54, 0x54, 0x54, 0x20}, // s	83
// 	{0x00, 0x04, 0x3F, 0x44, 0x40, 0x20}, // t	84
// 	{0x00, 0x3C, 0x40, 0x40, 0x20, 0x7C}, // u	85
// 	{0x00, 0x1C, 0x20, 0x40, 0x20, 0x1C}, // v	86
// 	{0x00, 0x3C, 0x40, 0x30, 0x40, 0x3C}, // w	87
// 	{0x00, 0x44, 0x28, 0x10, 0x28, 0x44}, // x	88
// 	{0x00, 0x1C, 0xA0, 0xA0, 0xA0, 0x7C}, // y	89
// 	{0x00, 0x44, 0x64, 0x54, 0x4C, 0x44}, // z	90
// 	{0x00, 0x00, 0x08, 0x77, 0x41, 0x00}, // {	91
// 	{0x00, 0x00, 0x00, 0xD7, 0xD7, 0x00}, // ¦	92
// 	{0x00, 0x00, 0x41, 0x77, 0x08, 0x00}, // }	93
// 	{0x00, 0x08, 0x04, 0x08, 0x08, 0x04}, // ~	94    (126 by ASCII)
// 	{0xFF, 0xFF, 0xFF, 0xFF, 0xFF, 0xFF}, // render	95    (127 by ASCII)
// 	{0x00, 0x00, 0x00, 0x00, 0x00, 0x00}, // sp 0  	 		
// 	/* end of normal char-set */
// 	/* put your own signs/chars here, edit special_char too */
// 	/* be sure that your first special char stand here */
// 	{0x00, 0x3A, 0x40, 0x40, 0x20, 0x7A}, // ь, 96 !!! Important: this must be special_char[0] !!!
// 	{0x00, 0x3D, 0x40, 0x40, 0x40, 0x3D}, // Ь	97
// 	{0x00, 0x21, 0x54, 0x54, 0x54, 0x79}, // д	98
// 	{0x00, 0x7D, 0x12, 0x11, 0x12, 0x7D}, // Д	99
// 	{0x00, 0x39, 0x44, 0x44, 0x44, 0x39}, // ц	100
// 	{0x00, 0x3D, 0x42, 0x42, 0x42, 0x3D}, // Ц	101
// 	{0x00, 0x02, 0x05, 0x02, 0x00, 0x00}, // °	102
// 	{0x00, 0x7E, 0x01, 0x49, 0x55, 0x73}, // Я  103
// 	{0x00, 0x7C, 0x10, 0x10, 0x08, 0x1C} // µ	104
// };												
//---------------------------------------------
unsigned char font8x6[51][6] = {
	//to get symbol from here need decrease ascii value to 47
	// 	{0x00, 0x08, 0x08, 0x08, 0x08, 0x08}, // -	13
	{0x00, 0x00, 0x36, 0x36, 0x00, 0x00}, // :  26		0	
	{0x00, 0x3E, 0x51, 0x49, 0x45, 0x3E}, // 0	16		1    ascii48
	{0x00, 0x00, 0x42, 0x7F, 0x40, 0x00}, // 1	17		2	
	{0x00, 0x42, 0x61, 0x51, 0x49, 0x46}, // 2	18		3
	{0x00, 0x21, 0x41, 0x45, 0x4B, 0x31}, // 3	19		4
	{0x00, 0x18, 0x14, 0x12, 0x7F, 0x10}, // 4	20		5	
	{0x00, 0x27, 0x45, 0x45, 0x45, 0x39}, // 5	21		6
	{0x00, 0x3C, 0x4A, 0x49, 0x49, 0x30}, // 6	22		7
	{0x00, 0x01, 0x71, 0x09, 0x05, 0x03}, // 7	23		8 ascii 55
	{0x00, 0x36, 0x49, 0x49, 0x49, 0x36}, // 8	24		9 
	{0x00, 0x06, 0x49, 0x49, 0x29, 0x1E}, // 9	25		10
	{0x00, 0x00, 0x60, 0x60, 0x00, 0x00}, // .  26		11
	{0x00, 0x00, 0x56, 0x36, 0x00, 0x00}, // ;  27		12
	{0x00, 0x08, 0x14, 0x22, 0x41, 0x00}, // <  28		13  ascii 60
	{0x00, 0x14, 0x14, 0x14, 0x14, 0x14}, // =  29		14
	{0x00, 0x00, 0x41, 0x22, 0x14, 0x08}, // >  30		15
	{0x00, 0x02, 0x01, 0x51, 0x09, 0x06}, // ?	31		16
	{0x00, 0x32, 0x49, 0x59, 0x51, 0x3E}, // @	32		17 ascii 64
	{0x00, 0x7C, 0x12, 0x11, 0x12, 0x7C}, // A	33		18
	{0x00, 0x7F, 0x49, 0x49, 0x49, 0x36}, // B	34		19
	{0x00, 0x3E, 0x41, 0x41, 0x41, 0x22}, // C	35		20
	{0x00, 0x7F, 0x41, 0x41, 0x22, 0x1C}, // D	36		21
	{0x00, 0x7F, 0x49, 0x49, 0x49, 0x41}, // E	37		22
	{0x00, 0x7F, 0x09, 0x09, 0x09, 0x01}, // F	38		23
	{0x00, 0x3E, 0x41, 0x49, 0x49, 0x7A}, // G	39		24
	{0x00, 0x7F, 0x08, 0x08, 0x08, 0x7F}, // H	40		25
	{0x00, 0x00, 0x41, 0x7F, 0x41, 0x00}, // I	41		26
	{0x00, 0x20, 0x40, 0x41, 0x3F, 0x01}, // J	42		27
	{0x00, 0x7F, 0x08, 0x14, 0x22, 0x41}, // K	43		28
	{0x00, 0x7F, 0x40, 0x40, 0x40, 0x40}, // L  44		29
	{0x00, 0x7F, 0x02, 0x0C, 0x02, 0x7F}, // M	45		30
	{0x00, 0x7F, 0x04, 0x08, 0x10, 0x7F}, // N	46		31
	{0x00, 0x3E, 0x41, 0x41, 0x41, 0x3E}, // O	47		32 ascii  79 -47=32(shift 47)
	{0x00, 0x7F, 0x09, 0x09, 0x09, 0x06}, // P	48		33
	{0x00, 0x3E, 0x41, 0x51, 0x21, 0x5E}, // Q	49		34
	{0x00, 0x7F, 0x09, 0x19, 0x29, 0x46}, // R	50		35
	{0x00, 0x46, 0x49, 0x49, 0x49, 0x31}, // S	51		36	ASCII 83
	{0x00, 0x01, 0x01, 0x7F, 0x01, 0x01}, // T	52		37
	{0x00, 0x3F, 0x40, 0x40, 0x40, 0x3F}, // U	53		38
	{0x00, 0x1F, 0x20, 0x40, 0x20, 0x1F}, // V	54		39  acssi 86
	{0x00, 0x3F, 0x40, 0x38, 0x40, 0x3F}, // W	55		40
	{0x00, 0x63, 0x14, 0x08, 0x14, 0x63}, // X	56		41
	{0x00, 0x07, 0x08, 0x70, 0x08, 0x07}, // Y	57		42
	{0x00, 0x61, 0x51, 0x49, 0x45, 0x43}, // Z	58		43
	{0x00, 0x00, 0x7F, 0x41, 0x41, 0x00}, // [	59		44
	{0x00, 0x55, 0x2A, 0x55, 0x2A, 0x55}, // | 60		45	ascii 92
	{0x00, 0x00, 0x41, 0x41, 0x7F, 0x00}, // ]	61		46
	{0xFF, 0xFF, 0xFF, 0xFF, 0xFF, 0xFF}, // render	95  47  (127 by ASCII)
	{0x00, 0x00, 0x00, 0x00, 0x00, 0x00}, // sp 0		48
	{0x00, 0x08, 0x08, 0x3E, 0x08, 0x08}, // +	11		49
	{0x00, 0x08, 0x08, 0x08, 0x08, 0x08}, // -	13	    50
	/* end of normal char-set */
};


// -----------------------------------------------
unsigned char a0;
unsigned char ColPosSt = 0;
unsigned char ColPosEnd = 127;
unsigned char PgPosSt = 0;
unsigned char PgPosEnd = 7;
unsigned char sec=0;
unsigned char zer =0;
unsigned char Ok=0;  //for menu choice
unsigned char Line = 0; //for menu choice
unsigned int adc_value=0;
unsigned int adt_value=0;
//WARNING: This Font Require X-GLCD Lib.
//         You can not use it with MikroE GLCD Lib.

//Font Generated by MikroElektronika GLCD Font Creator 1.2.0.0
//MikroElektronika 2011
//http://www.mikroe.com
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
int main (void)
{
   //-------------TEST SECTION----------------------------------
Blink_13(4);  // the led 13 will blink () times
   
   //---------------END OF TEST SECTION
   
   //------------------start     pulse section
   ShiftRegReset(); //
   ShiftRegister2(24); //UNCOMMENT FOR W/O DISPLAY DUMMI
  
   //-------------------end of pulse section --------------------
   _delay_ms(2222);	
   Blink_13(2);  // the led 13 will blink () times
   
   //unsigned int adc_value;
   //------------- Ports settings ----------------------
   DDRB = 0xFF;//set port B to output level FFFFFF
   DDRC = 0xFF;  
   DDRD = 0xFF;
   DDRC =(0<<DDC0)|(0<<DDC1);  
   PORTB = !(0x00); //set port B pins state  to Low 
   PORTD = !(0x00);//set port D pins state  to ~ high
   PORTC = (0xFF);  //set port C pins state  to low and pull-up inputs
   // --------------- & of Port settings 
   //-----------speed
   TWBR = (0x02);
   TWSR = (1<<TWPS1) | (1<<TWPS0);
   //-----------------
	I2C_Start();
	I2C_SLA_W();
	//----------------------------------------------
	//-------------start display settings
	I2C_cnt_COM();
	data=0xAF;	//power on
	I2C_DATA();
	//----------------------------------------------
//----------Contrast value------------
	I2C_cnt_COM();
	data=0x81;						//Double byte command to select 1 out of 256
	I2C_DATA();						// 	contrast steps. Contrast increases as the value increases.
	I2C_cnt_COM();
	data=0x0F;						// 	
	I2C_DATA();
	//---------------------------------
	I2C_cnt_COM();                  //0x8D, 0x14,      // Set DC-DC enable
	data=0x8D;						
	I2C_DATA();
	I2C_cnt_COM();                  //0x8D, 0x14,      
	data=0x14;
	I2C_DATA();
	//------------------------------------	

	//--------------------------------
	I2C_cnt_COM();
	data=0xA6;						//
	I2C_DATA();						// 	A6h, X[0]=0b: Normal display (RESET)
	_delay_ms(22);				// 	0 in RAM: OFF in display panel
									// 	1 in RAM: ON in display panel
									// 	A7h, X[0]=1b: Inverse display
									// 	0 in RAM: ON in display panel
									// 	1 in RAM: OFF in display panel
	
	I2C_Stop();	
	//------------    Demo -------------------------
	//-----------------
	I2C_Start();
	I2C_SLA_W();
	//----------------------------------------------
	
		Clearscreen();
		Blink_yellow_n(5);
		Buttons();
		sei();
		while(1)
		{
			MenuPrint();
			Arrow();
			Blink_red_n(3);
			//MenuOut();
		}
	

I2C_Stop();	   
}

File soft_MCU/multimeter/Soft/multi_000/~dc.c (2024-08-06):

/*
 * adc.c
 *
 * Created: 11/25/2020 10:54:14 AM
 *  Author: john
 */ 
#include "adc.h"
//-------------
void ADC_Init(void) //initial

{
	ADCSRA |= (1<<ADEN) // adc enable ?????????? ????????????? ??? 
	| (1<<ADPS2)|(1<<ADPS1)|(1<<ADPS0);//divider 128 = 64kHz ???????? 128 = 64???
	
	ADMUX |= (1<<REFS1)|(1<<REFS0); // inside ref voltage 1.1V  port ADC0 ?????????? ???????? ?? 2,56?, ???? ADC0	
	
}
//-------------------------
//-------------------------
unsigned int ADC_convert (void)   //adc start counting process 
{
	ADCSRA |= (1<<ADSC); //start coversion (When the conversion is complete, it returns to zero). ???????? ??????????????
	while((ADCSRA & (1<<ADSC))); //check, does the conversion finished ???????? ??????????? ?? ???????-???????? ??????????????
	return (unsigned int) ADC;	
}
//-------------------------
